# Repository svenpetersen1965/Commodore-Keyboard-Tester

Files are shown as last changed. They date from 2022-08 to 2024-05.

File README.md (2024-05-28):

# Commodore-Keyboard-Tester
This is a tester for Commodore matrix keyboards for the following compurters:
* C64
* VIC-20
* PET/CBM
* C16
* C128
* C128D
* SX-64

It can measure the resistance of every single key, which requires a multimeter and two 4mm lab cables.

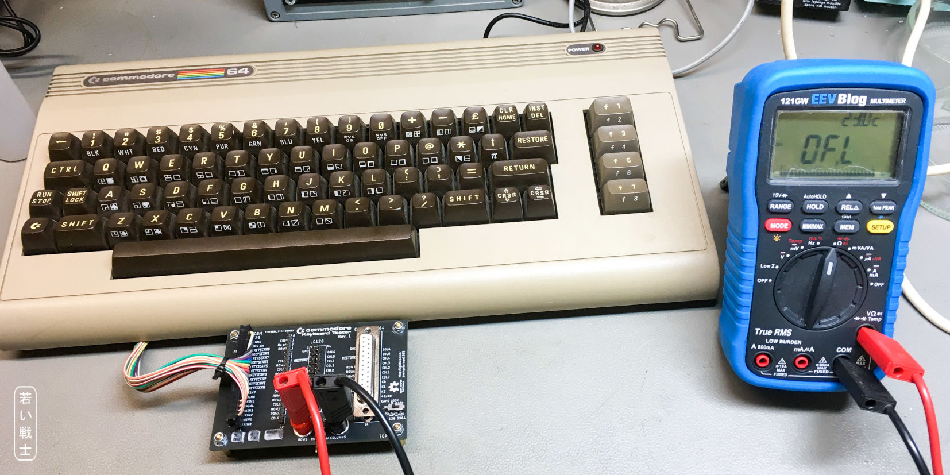
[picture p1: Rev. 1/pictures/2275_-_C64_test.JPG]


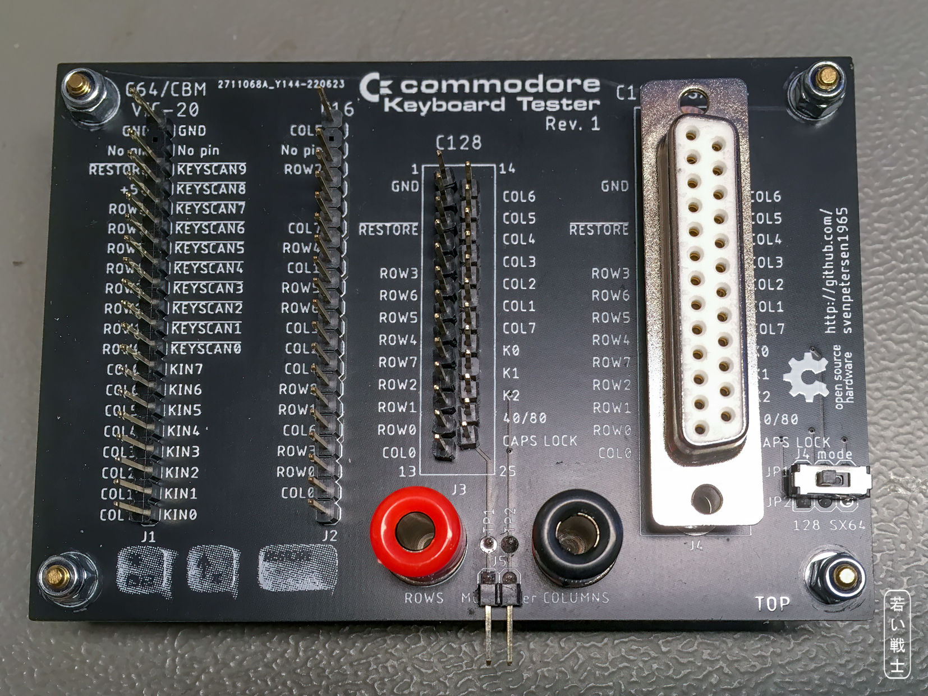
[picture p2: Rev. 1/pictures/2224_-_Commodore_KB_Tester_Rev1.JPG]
Commodore Keyboard Tester


# Case (3D printed)
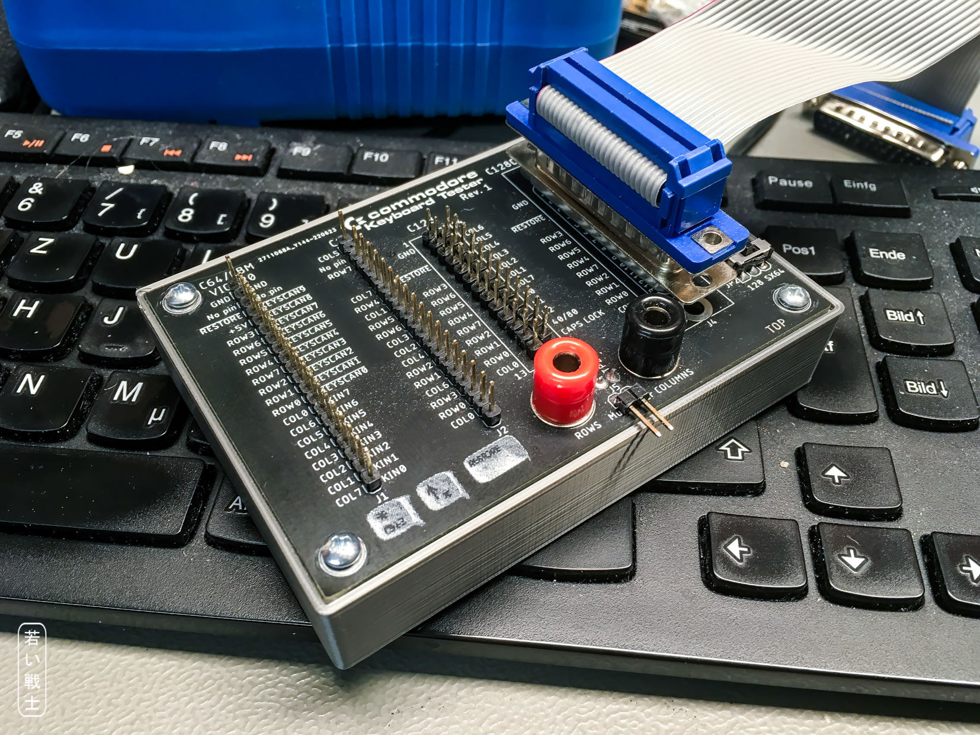
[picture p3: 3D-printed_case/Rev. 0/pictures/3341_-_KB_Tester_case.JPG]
Commodore Keyboard Tester


The 3D printed case offers a better protection of the bottom side and looks a bit nicer, than the stand off solution. It works with all released versions (100mm x
70mm PCB). 

Recommended screws are 4 each of C2.9 x 6.5 (self cutting, DIN 7981). The drill diameter is 2.5mm.

In case it is desired to use 2mm lab jacks, a 3mm deeper case (Rev. 2) has been released.

# Rev. 2
Rev. 2 is mainly a nicer looking silkscreen, than Rev. 1. Technically, this version is not any upgrade. 

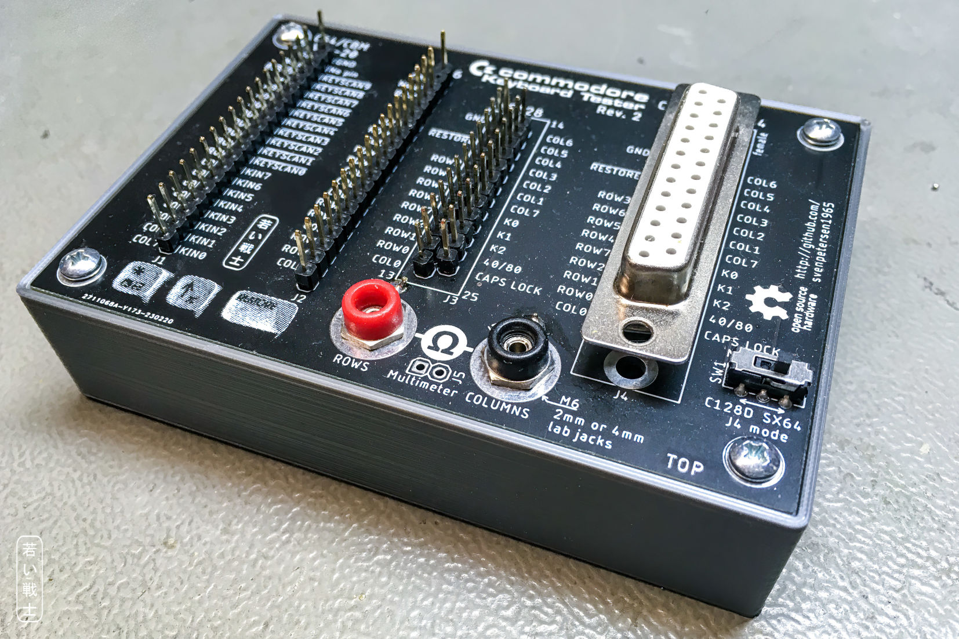
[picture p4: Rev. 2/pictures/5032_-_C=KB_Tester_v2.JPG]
Commodore Keyboard Tester Rev. 2


# Info about rejuvenation keyboard rubber
As I said in the documentation, one reason for bad keys is the oil that is sweating from the conductive rubbers over the decades. This can be removed by soaking the rubbers in a mild caustic solution for at least 24hours.

Jeff Birt did some great research on this topic, which cou can find here:

<a href="https://youtu.be/n9gGz2n-sBU">Hey Birt! (Youtube): Resistance is futile Rejuvenating vintage computer keyboard key contacts</a>

Instead of ammonia, I am using a lye (NaOH) solution and I wrote somethng about it on my website:

<a href="http://tech.guitarsite.de/conductive_rubber.html">Rejuvenating The Conductive Rubber In a (Commodore) Keyboard</a>

After treating the keyboard rubbers, it might make sense to measure their resistance before installing them in the keyboard again. I found Jeff Birt's ficture quite nice for doing so. 

https://github.com/Jeff-Birt/C64_C128_Amiga_Mitsumi_Key_Tester

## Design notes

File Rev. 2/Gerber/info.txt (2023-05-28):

      
       Board: Commodore_KB_Tester
       Rev.:  2
  
       Files:
       ======
  
       All Gerber files are generated in extended gerber format (RS274X)
       *.TOP        : Film top copper
       *.BOT        :  -"- bottom copper
       *.STC        :  -"- top soldermask 
       *.STS        :  -"- bottom soldermask
       *.PLC        :  -"- silk screen top
       *.DK         : Drills plated Through (Excellon)
       *.NDK        : Drills not plated Through (Excellon)
       *.OUT        : Board outline

       Board Size:
       ===========
       Length     :   100.0 mm
       Width      :   70.0 mm
       Thickness  :   1.6 mm
       Material   :   FR 4
       Copper     :   35 um
       Surface    :   HASL
       
       Remarks:
       ========

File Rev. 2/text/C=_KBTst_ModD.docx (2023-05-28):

Commodore Keyboard Tester Rev. 2

Module Description

# 1. Introduction

They keyboard tester aims at testing Commodore matrix keyboards with an ohm meter (multi meter) without disassembling the keyboard.

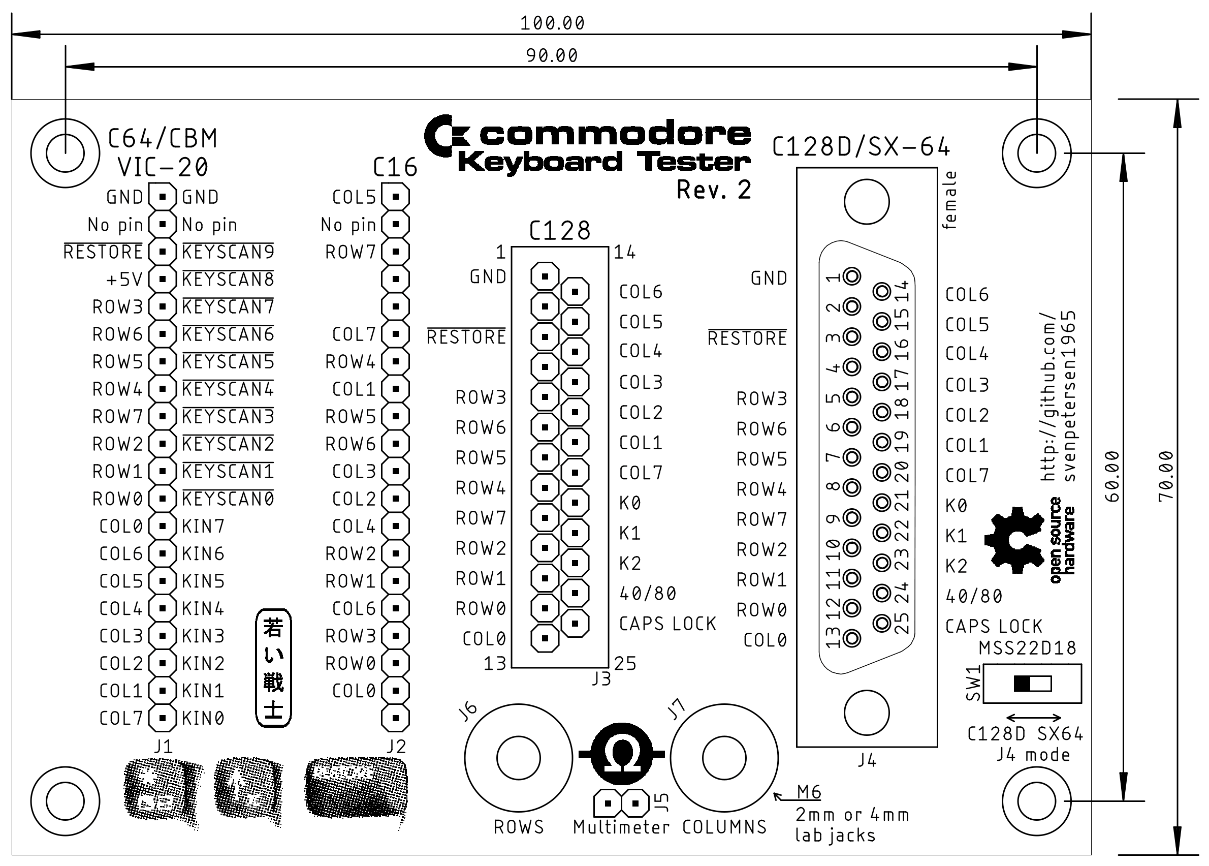
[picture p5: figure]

Figure 1: Commodore Keyboard Tester Rev. 1

Each button in a matrix keyboard is connected to one column and one row signal. If all rows are connected to on lead of the multi meter and all columns are connected to the other lead of the multimeter, a key press will connect both sides, no matter, which key it is. Assuming, that no 2nd key is pressed, the reading on the ohm meter is the impedance of the pressed key plus the traces and cables.

# 2. Keyboard Matrices

## 2.1. C64/VIC-20/PET

The VIC-20, C64, and PET (Graphic and Business Keyboard) have the same connector (a 20 pin header with the 2nd pin missing as a keying for the direction.

Connection | C64/VIC20 | Pin | Pin | PET/CBM | Connection
COLS | GND | 1 | 12 | GND | (COLS)
- | No pin | 2 | 11 | No pin | -
ROWS | RESTORE | 3 | 10 | | ROWS
(ROWS) | +5V | 4 | 9 | | ROWS
ROWS | ROW3 | 5 | 8 | | ROWS
ROWS | ROW6 | 6 | 7 | | ROWS
ROWS | ROW5 | 7 | 6 | | ROWS
ROWS | ROW4 | 8 | 5 | | ROWS
ROWS | ROW7 | 9 | 4 | | ROWS
ROWS | ROW2 | 10 | 3 | | ROWS
ROWS | ROW1 | 11 | 2 | | ROWS
ROWS | ROW0 | 12 | 1 | | ROWS
COLS | COL0 | 13 | J | KIN7 | COLS
COLS | COL6 | 14 | H | KIN6 | COLS
COLS | COL5 | 15 | F | KIN5 | COLS
COLS | COL4 | 16 | E | KIN4 | COLS
COLS | COL3 | 17 | D | KIN3 | COLS
COLS | COL2 | 18 | C | KIN2 | COLS
COLS | COL1 | 19 | B | KIN1 | COLS
COLS | COL7 | 20 | A | KIN0 | COLS

The PET/CBM-Keyboard connector has an unusual pin numbering, but the table above shows, which pin numbers are identical. Pin 4 of the C64/VIC-20 connector (+5) is not connected within the keyboard and pin 12 (GND) of the PET/CBM keyboard. Connecting them the way shown in the table, allows testing both kinds of keyboard at the same pin header.

## 2.2. C16

The C16 keyboard matrix is quite different from the C64/VIC-20 keyboard. It is missing the RESTORE key and the +5V and no key is referenced to GND.

Connection | Signal | Pin
COLS | COL5 | 1
- | No pin | 2
ROWS | ROW7 | 3
- | GND | 4
- | - | 5
COLS | COL7 | 6
ROWS | ROW4 | 7
COLS | COL1 | 8
ROWS | ROW5 | 9
ROWS | ROW6 | 10
COLS | COL3 | 11
COLS | COL2 | 12
COLS | COL4 | 13
ROWS | ROW2 | 14
ROWS | ROW1 | 15
COLS | COL6 | 16
ROWS | ROW3 | 17
ROWS | ROW0 | 18
COLS | COL0 | 19
- | - | 20

## 2.3. C128

The C128 has a keyboard connector, which is a pin header (0.65 sq) that fits on the footprint of a female D-SUB connector. The pin numbering is identical to such a D-SUB connector. According to Bil Herd, this pin header was custom made for Commodore.

Connection | Signal | Pin | Pin | Signal | Connection
COLS | GND | 1 | 14 | COL6 | COLS
- | No Pin | 2 | 15 | COL5 | COLS
ROWS | | 3 | 16 | COL4 | COLS
- | +5V | 4 | 17 | COL3 | COLS
ROWS | ROW3 | 5 | 18 | COL2 | COLS
ROWS | ROW6 | 6 | 19 | COL1 | COLS
ROWS | ROW5 | 7 | 20 | COL7 | COLS
ROWS | ROW4 | 8 | 21 | K0 | COLS
ROWS | ROW7 | 9 | 22 | K1 | COLS
ROWS | ROW2 | 10 | 23 | K2 | COLS
ROWS | ROW1 | 11 | 24 | 40/80 | ROWS
ROWS | ROW0 | 12 | 25 | CAPS LOCK | ROWS
COLS | COL0 | 13 | - | - | -

, 40/80 and CAPS LOCK are referenced to GND (Pin 1). K0…K2 are additional columns, they are connected to the 24 extra keys, which are not present in the C64 mode.

## 2.4. C128D & SX-64

The SX-64 keyboard cable does not fit with the female D-SUB 25 connector. Testing an SX-25 Keyboard requires an extra cable: two male D-SUB 25 connectors on a ribbon cable. This allows to connect the tester directly to the keyboard.

Connection | C128D | Pin | SX-64 | Connection
COLS | GND | 1 | GND | COLS
- | No Pin | 2 | No Pin | -
ROWS | | 3 | | ROWS
- | +5V | 4 | +5V | -
ROWS | ROW3 | 5 | ROW3 | ROWS
ROWS | ROW6 | 6 | ROW6 | ROWS
ROWS | ROW5 | 7 | ROW5 | ROWS
ROWS | ROW4 | 8 | ROW4 | ROWS
ROWS | ROW7 | 9 | ROW7 | ROWS
ROWS | ROW2 | 10 | ROW2 | ROWS
ROWS | ROW1 | 11 | ROW1 | ROWS
ROWS | ROW0 | 12 | ROW0 | ROWS
COLS | COL0 | 13 | COL0 | COLS
COLS | COL6 | 14 | COL6 | COLS
COLS | COL5 | 15 | COL5 | COLS
COLS | COL4 | 16 | COL4 | COLS
COLS | COL3 | 17 | COL3 | COLS
COLS | COL2 | 18 | COL2 | COLS
COLS | COL1 | 19 | COL1 | COLS
COLS | COL7 | 20 | COL7 | COLS
COLS | K0 | 21 | SHIFT LOCK | ROWS
COLS | K1 | 22 | LED (+) | COLS
COLS | K2 | 23 | GND | COLS
ROWS | 40/80 | 24 | GND | COLS
ROWS | CAPS LOCK | 25 | n.c. | (ROWS)

n.c.: not connected

, 40/80, CAPS LOCK and SHIFT LOCK are referenced to GND (Pin 1). The LED (+) is also referenced to GND, it will not be tested. Pin 21 and pin 24 are different for the C128D and the SX-64. They require to be configurable with jumpers or a slide switch (option).

# 3. Assembly

## 3.1. The C64 and C16 connector (J1 and J2)

These connectors are standard 20 pin headers with pin 2 pulled out. It could be cut off, I prefer to pull it with pliers, though.

## 3.2. The C128 connector (J3)

J3 is actually a square pin header (0.65mm) with the footprint of a 25 pin DSub (male). My first attempt was cutting the frame off a vertical DSub connector and using it for J3, but it did not work out, since the pins of the DSub are too thick to fit into the keyboard connector. It is not helpful to ruin the keyboard connector.

I had a short conversation with Bil Herd (the C128 engineer at Commodore) about the pin header. He said, it was custom made for Commodore. So, it cannot be sourced anywhere.

A DSub connector has a pin pitch of 110 mil, so the standard 100 mil pin header does not fit, either. A solution, that is not beautiful, but practical is using 25 single pin headers and insert them into the keyboard connector before soldering.

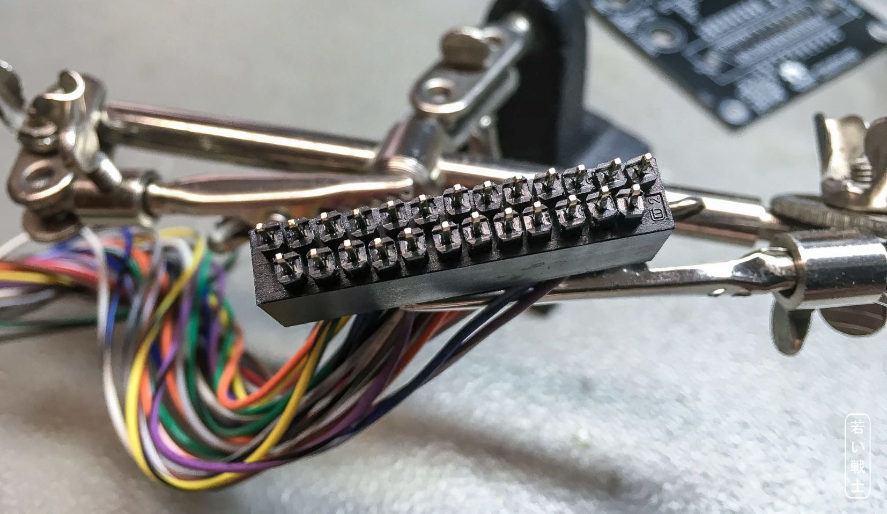
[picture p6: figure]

Figure 2: Alignment of the pins in a C128 keyboard connector

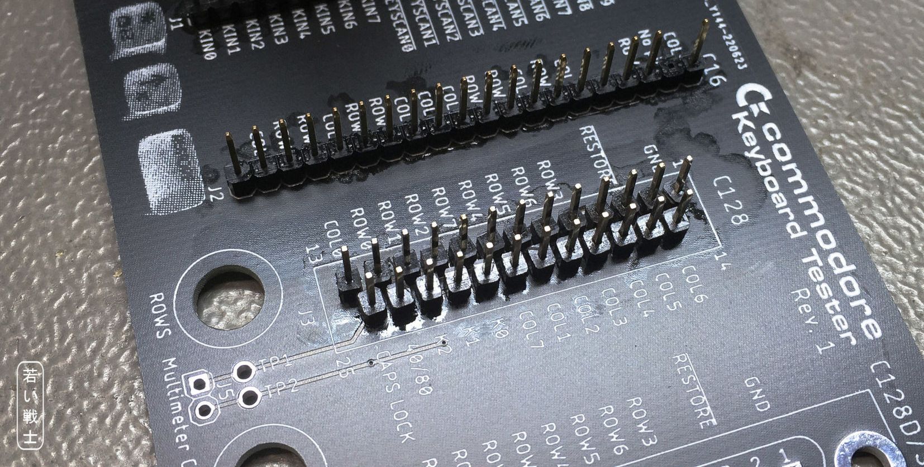
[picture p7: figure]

Figure 3: Soldered in C128 keyboard header (25 single pin headers) PCB Rev. 1

## 3.3. The C128D/SX-64 connector (J4)

This is a 25p DSub (female) connector. No further comments required.

## 3.4. 2mm/4mm Lab Jack for the Multimeter

The lab jacks for the multimeter have to be connected the solder pads beside the Lab jack footptint with a short piece of wire. Some sorts are pretty hard to solder and tend to deform/melt. It is a good idea to remove as many parts as possible before soldering.

Non-insulated lab jacks can be just screwed in. The big solder pad is connected to the circuitry, so there is no extra cable required.

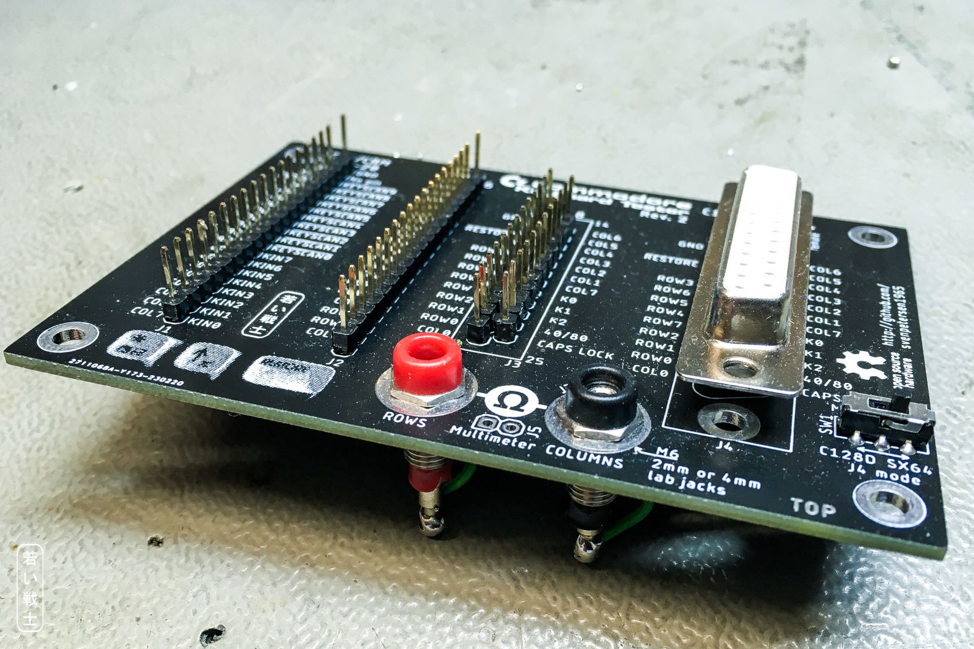
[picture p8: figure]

Figure 4: 2mm jacks for the multimeter

The lab jacks should be installed with all plastic parts on the component side of the PCB to keep the profile below the PCB as low as possible. 2mm and 4mm lab jacks with an M6 thread are suitable.

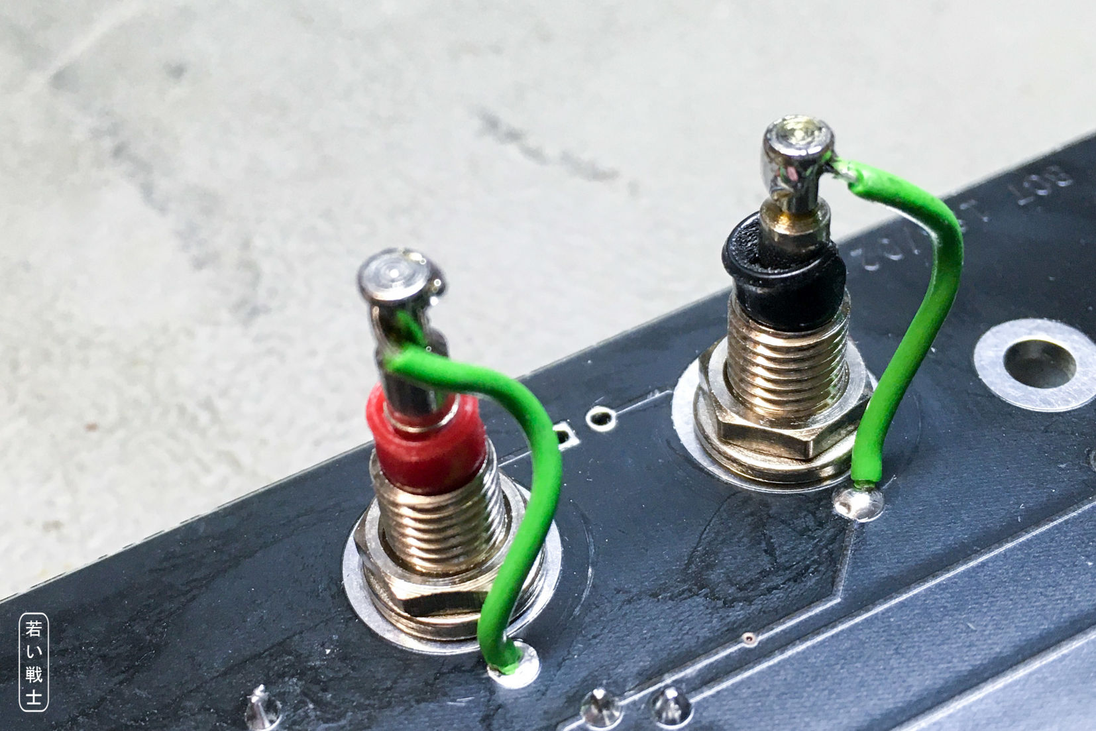
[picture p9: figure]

Figure 5: 2mm lab jack connected with a piece of wire

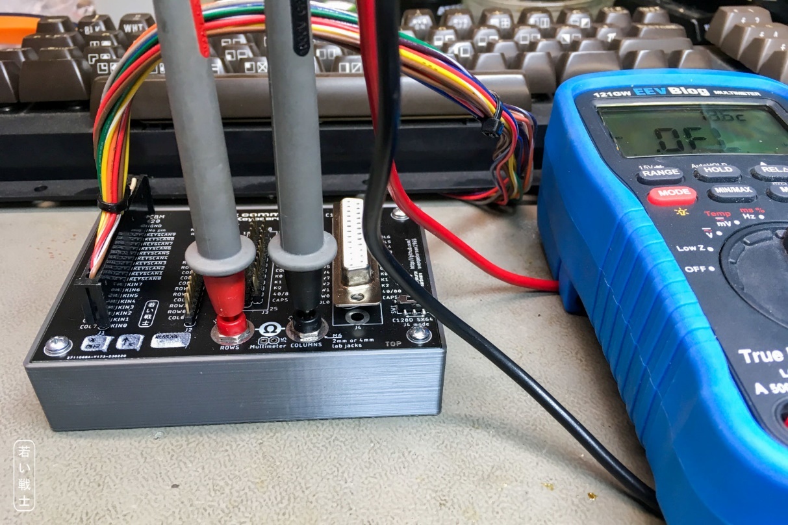
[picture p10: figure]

Figure 6: Keyboard Tester with 2mm jacks "in situ"

2mm lab jacks directly connect to the leads of a multimeter.

## 3.5. Multimeter Pin Header (J5)

J5 is a standard pin header, which can be either vertical or a 90°-type. It is optional. I am using it with a one pin Dupont connector on a cable with a 4mm plug and that is pretty handy, too. However, J5 is in parallel with the lab jacks and it is optional.

## 3.6. The C128D/SX-64 selection switch

The mini slide switch has a 2.54mm pitch in each row of pins. The distance of the rows is off pitch, though. This way, it also fits two 3pin 2.54mm jumpers.

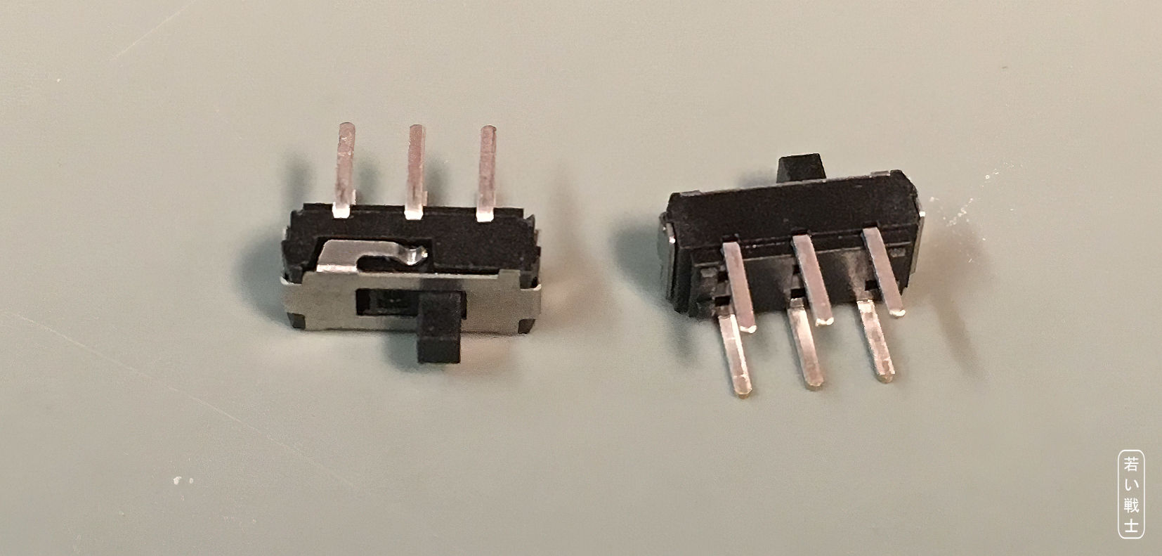
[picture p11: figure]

Figure 7: Mini slide switch

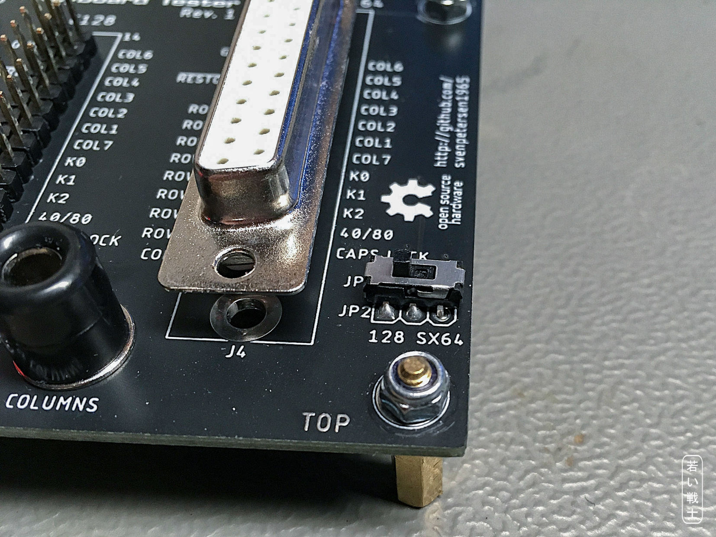
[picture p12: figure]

Figure 8: Slide switch placed instead of JP1 and JP2

These mini slide switches can be found on Amazon, Ebay and AliExpress. A possible search term is “mini slide switch dpdt” or “MSS22D18”, which will not show these switches exclusively, but it should not be too hard to find the right ones.

## 3.7. The SX-64 Keyboard Cable

The original SX-64 keyboard cable does not fit with the female DSub on the Keyboard Tester, but a male

## 3.8. The 3D-printed case

For the 2mm lab jacks, the case needs to be 3mm deeper than for Rev. 0 and 1. If 4mm lab jacks are used, the Rev.0 case is still suitable (which saves a little bit of printing time.

Recommended screws: 4 each of 2.9mm x 6.5mm (self-taping) screws for sheet metal (C 2,9x6,5H, DIN 7981)

# 4. The Use of the Keyboard Tester

A multimeter is required for using this keyboard tester. A good impedance is between 0Ω and a few 100 Ω. Probably, a keyboard works with even up to 3kΩ, but I would consider it as critical. Also, the different computers use different interface chips (VIA, CIA etc.) and even scanning is a bit different, so the limit for “good” might be different. In my opinion, everything above 600Ω requires inspection. 2kΩ might still work.

The keyboard is connected to the proper pin header, the multimeter is set to continuity test (“beeper”) mode or a low Ohms range. Every single key of the keyboard is pressed, one at a time and the value is read from the multimeter. If a key does not produce a reading in continuity test mode, switch to normal Ohms mode. This is slower, but sometimes the range in continuity test mode is too low to show a reading. The 121GW will display up to 550Ω, while the VC160 displays up to 400Ω in the continuity tester mode.

With the 121GW, it is possible to set the range from auto to kΩ, which will speed up the measurement from about 5 seconds to “almost immediate”.

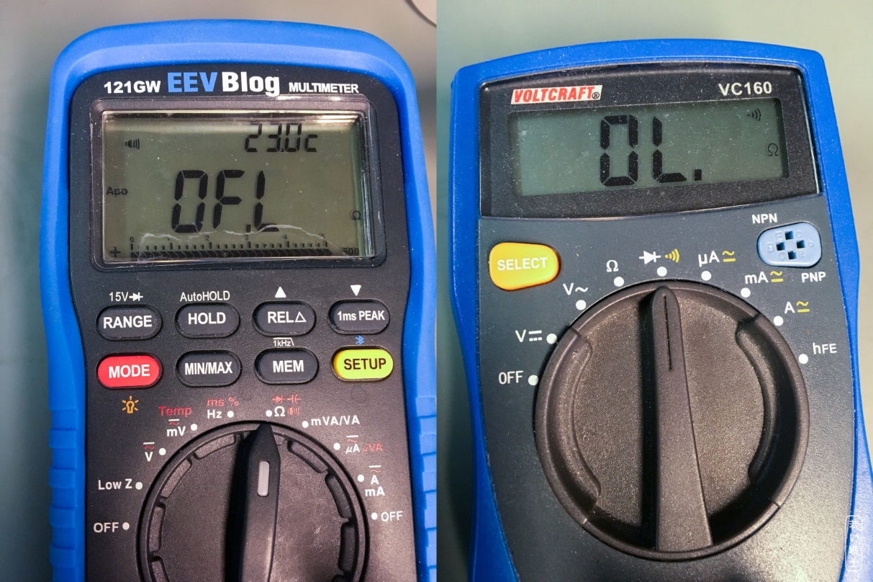
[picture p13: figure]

Figure 9: Multimeters in continuity test mode

A key is high impedance, and now?

There are different reasons for that, all require opening the keyboard and inspecting the thing.

Sometimes, dirt has collected under the failing key. That can be fixed easily. Carefully remove the dust/dirt. You can use isopropanol (rubbing alcohol, IPA) on the conductive rubbers and also on a golden surface PCB. Do not rub IPA hard on carbon contact key pads. The carbon contact could be damaged. It requires a more careful use of IPA or maybe even just demineralized water without a detergent.

Many keyboard PCBs use a “two layers on one side” technology with conductive bridges adhered to some contact points, that are crossing several copper traces. Those can get high impedance. I have fixed this kind of problems with soldering botch wires to the poorly contacted copper trace. Those botch wires should run on the bottom side of the PCB to not mechanically interfere with the keyboard. This might require drilling little holes for switching sides.

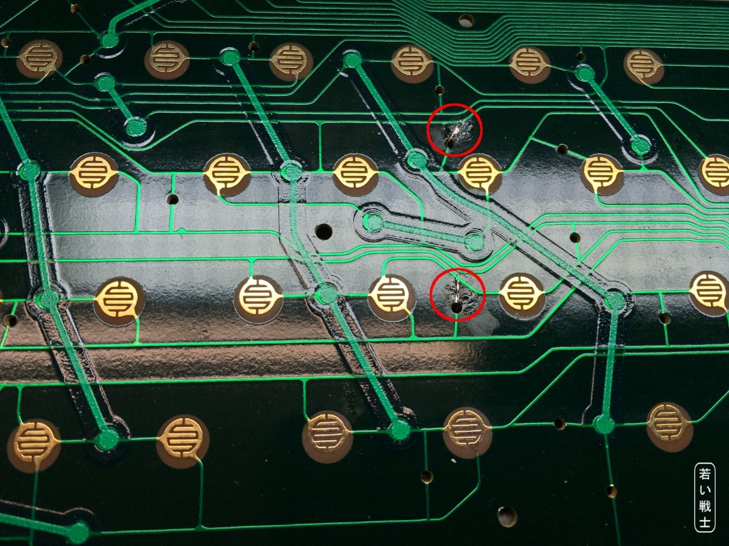
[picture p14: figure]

Figure 10: Botch wire repair (top side) solder joints

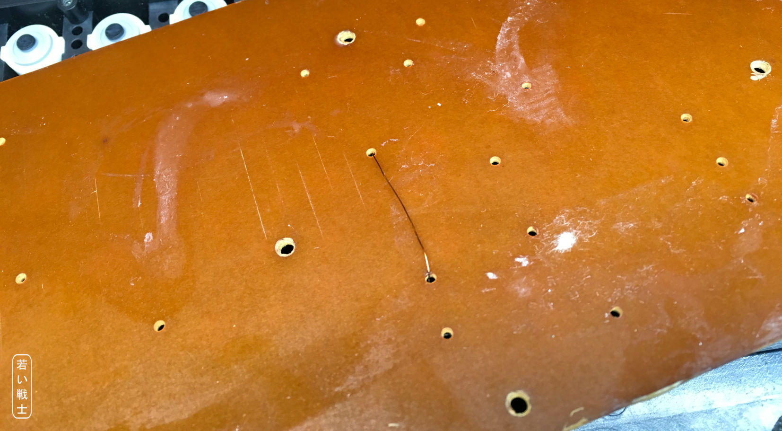
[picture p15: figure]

Figure 11: Botch wire repair (bottom side)

In this case, I have made use of the already existing drills in the PCB.

Jeff Birt from the “Hey Birt!” Youtube channel has done some research on aging conductive keyboard rubbers. He found out, that high impedance keyboard rubbers are caused by oils, that are escaping the rubber. He said, that removing theses oils requires a mild caustic solution.

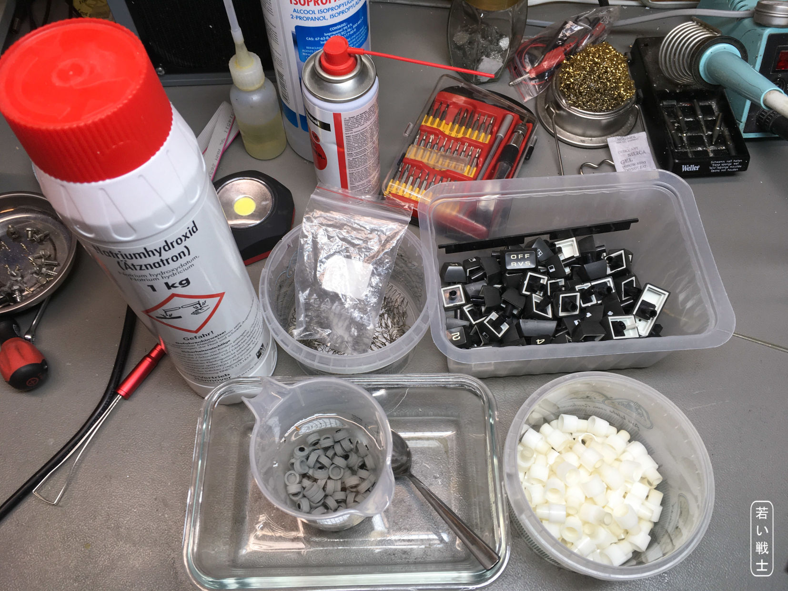
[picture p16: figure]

Figure 12: Rejuvenation the keyboard rubbers with a NaOH (lye) solution

I am using a lye (NaOH/sodium hydroxide) solution (1 teaspoon in 125ml of demineralized water). The keyboard rubbers need to be submerged in it for about 24 hours. After this treatment, they should be rinsed carefully (use a big enough sieve to not lose any) in tap water and finally in demineralized water. Finally, let it them dry on a kitchen paper over night.

This is quite a bit of work, but well worth it. Once, I had tried to get the rubbers out without disassembling the keyboard on a C16 keyboard and accidentally destroyed one. Also, it might be good to clean every single part of a keyboard on a newly acquired computer, anyway.

# 5. Revision History

## 5.1. Rev. 0

- The prototype worked with all, except the SX-64 Keyboard.

## 5.2. Rev. 0 → Rev. 1

- Jumper/Switch added for configuring the C128D or the SX-64 keyboard
- Fully functional

## 5.3. Rev. 1 → Rev. 2

- Improvement of the silk screen print
- The functionality is identical to Rev. 1

C=_KBTst_ModD.docx 28.05.2023 13:55 Drafted by Sven Petersen Page 2 of 2 Doc.-No.: 188-6-01-02

C=_KBTst_ModD.docx 28.05.2023 13:55 Drafted by Sven Petersen Page 1 of 1 Doc.-No.: 000-6-00-00

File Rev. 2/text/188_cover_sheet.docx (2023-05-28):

Project Documentation

Project number: 188

Revision: 2

Date: 29.01.2023


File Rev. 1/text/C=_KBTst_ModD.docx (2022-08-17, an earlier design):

Commodore Keyboard Tester Rev. 1

Module Description

# Introduction

They keyboard tester aims at testing Commodore matrix keyboards with an ohm meter (multi meter) without disassembling the keyboard.

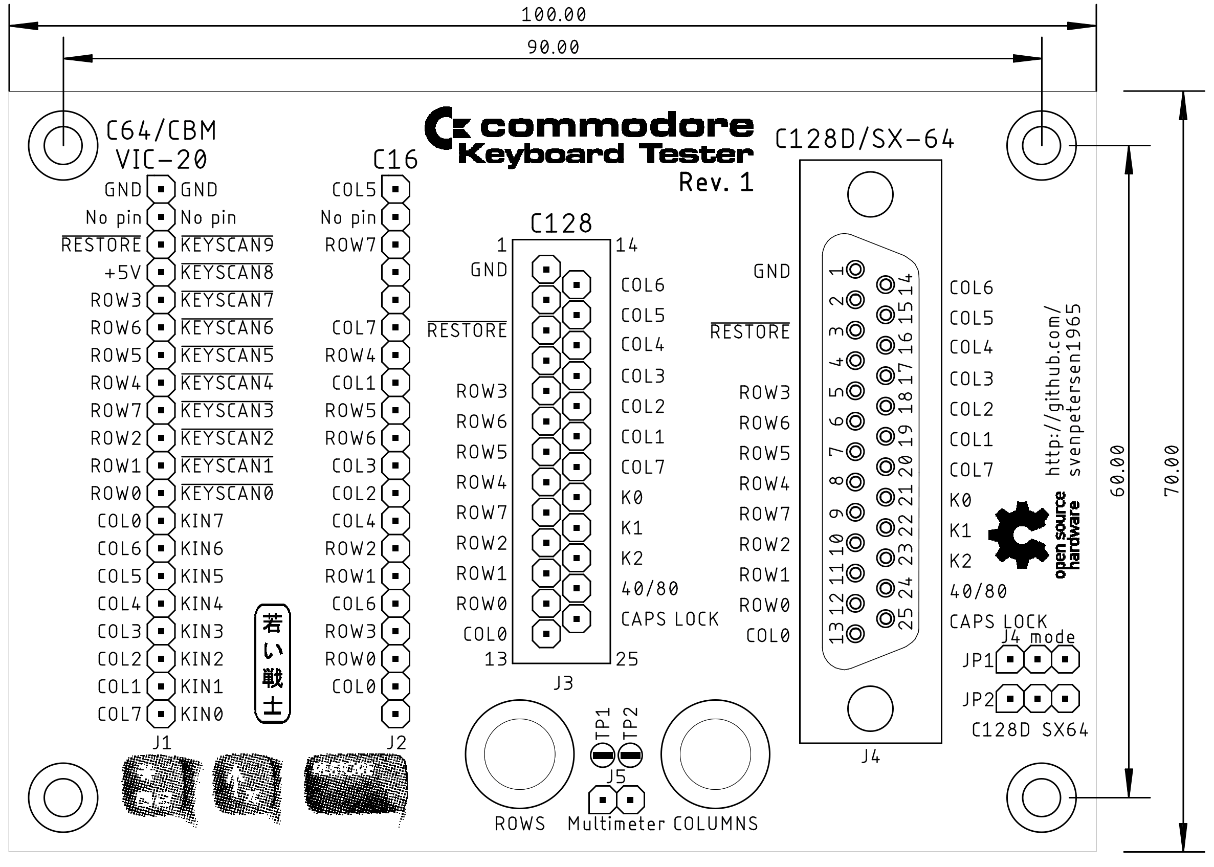
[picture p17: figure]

Figure 1: Commodore Keyboard Tester Rev. 1

Each button in a matrix keyboard is connected to one column and one row signal. If all rows are connected to on lead of the multi meter and all columns are connected to the other lead of the multimeter, a key press will connect both sides, no matter, which key it is. Assuming, that no 2nd key is pressed, the reading on the ohm meter is the impedance of the pressed key plus the traces and cables.

# Keyboard Matrices

## C64/VIC-20/PET

The VIC-20, C64, and PET (Graphic and Business Keyboard) have the same connector (a 20 pin header with the 2nd pin missing as a keying for the direction.

Connection | C64/VIC20 | Pin | Pin | PET/CBM | Connection
COLS | GND | 1 | 12 | GND | (COLS)
- | No pin | 2 | 11 | No pin | -
ROWS | RESTORE | 3 | 10 | | ROWS
(ROWS) | +5V | 4 | 9 | | ROWS
ROWS | ROW3 | 5 | 8 | | ROWS
ROWS | ROW6 | 6 | 7 | | ROWS
ROWS | ROW5 | 7 | 6 | | ROWS
ROWS | ROW4 | 8 | 5 | | ROWS
ROWS | ROW7 | 9 | 4 | | ROWS
ROWS | ROW2 | 10 | 3 | | ROWS
ROWS | ROW1 | 11 | 2 | | ROWS
ROWS | ROW0 | 12 | 1 | | ROWS
COLS | COL0 | 13 | J | KIN7 | COLS
COLS | COL6 | 14 | H | KIN6 | COLS
COLS | COL5 | 15 | F | KIN5 | COLS
COLS | COL4 | 16 | E | KIN4 | COLS
COLS | COL3 | 17 | D | KIN3 | COLS
COLS | COL2 | 18 | C | KIN2 | COLS
COLS | COL1 | 19 | B | KIN1 | COLS
COLS | COL7 | 20 | A | KIN0 | COLS

The PET/CBM-Keyboard connector has an unusual pin numbering, but the table above shows, which pin numbers are identical. Pin 4 of the C64/VIC-20 connector (+5) is not connected within the keyboard and pin 12 (GND) of the PET/CBM keyboard. Connecting them the way shown in the table, allows testing both kinds of keyboard at the same pin header.

## C16

The C16 keyboard matrix is quite different from the C64/VIC-20 keyboard. It is missing the RESTORE key and the +5V and no key is referenced to GND.

Connection | Signal | Pin
COLS | COL5 | 1
- | No pin | 2
ROWS | ROW7 | 3
- | GND | 4
- | - | 5
COLS | COL7 | 6
ROWS | ROW4 | 7
COLS | COL1 | 8
ROWS | ROW5 | 9
ROWS | ROW6 | 10
COLS | COL3 | 11
COLS | COL2 | 12
COLS | COL4 | 13
ROWS | ROW2 | 14
ROWS | ROW1 | 15
COLS | COL6 | 16
ROWS | ROW3 | 17
ROWS | ROW0 | 18
COLS | COL0 | 19
- | - | 20

## C128

The C128 has a keyboard connector, which is a pin header (0.65 sq) that fits on the footprint of a female D-SUB connector. The pin numbering is identical to such a D-SUB connector. According to Bil Herd, this pin header was custom made for Commodore.

Connection | Signal | Pin | Pin | Signal | Connection
COLS | GND | 1 | 14 | COL6 | COLS
- | No Pin | 2 | 15 | COL5 | COLS
ROWS | | 3 | 16 | COL4 | COLS
- | +5V | 4 | 17 | COL3 | COLS
ROWS | ROW3 | 5 | 18 | COL2 | COLS
ROWS | ROW6 | 6 | 19 | COL1 | COLS
ROWS | ROW5 | 7 | 20 | COL7 | COLS
ROWS | ROW4 | 8 | 21 | K0 | COLS
ROWS | ROW7 | 9 | 22 | K1 | COLS
ROWS | ROW2 | 10 | 23 | K2 | COLS
ROWS | ROW1 | 11 | 24 | 40/80 | ROWS
ROWS | ROW0 | 12 | 25 | CAPS LOCK | ROWS
COLS | COL0 | 13 | - | - | -

, 40/80 and CAPS LOCK are referenced to GND (Pin 1). K0…K2 are additional columns, they are connected to the 24 extra keys, which are not present in the C64 mode.

## C128D & SX-64

The SX-64 keyboard cable does not fit with the female D-SUB 25 connector. Testing an SX-25 Keyboard requires an extra cable: two male D-SUB 25 connectors on a ribbon cable. This allows to connect the tester directly to the keyboard.

Connection | C128D | Pin | SX-64 | Connection
COLS | GND | 1 | GND | COLS
- | No Pin | 2 | No Pin | -
ROWS | | 3 | | ROWS
- | +5V | 4 | +5V | -
ROWS | ROW3 | 5 | ROW3 | ROWS
ROWS | ROW6 | 6 | ROW6 | ROWS
ROWS | ROW5 | 7 | ROW5 | ROWS
ROWS | ROW4 | 8 | ROW4 | ROWS
ROWS | ROW7 | 9 | ROW7 | ROWS
ROWS | ROW2 | 10 | ROW2 | ROWS
ROWS | ROW1 | 11 | ROW1 | ROWS
ROWS | ROW0 | 12 | ROW0 | ROWS
COLS | COL0 | 13 | COL0 | COLS
COLS | COL6 | 14 | COL6 | COLS
COLS | COL5 | 15 | COL5 | COLS
COLS | COL4 | 16 | COL4 | COLS
COLS | COL3 | 17 | COL3 | COLS
COLS | COL2 | 18 | COL2 | COLS
COLS | COL1 | 19 | COL1 | COLS
COLS | COL7 | 20 | COL7 | COLS
COLS | K0 | 21 | SHIFT LOCK | ROWS
COLS | K1 | 22 | LED (+) | COLS
COLS | K2 | 23 | GND | COLS
ROWS | 40/80 | 24 | GND | COLS
ROWS | CAPS LOCK | 25 | n.c. | (ROWS)

n.c.: not connected

, 40/80, CAPS LOCK and SHIFT LOCK are referenced to GND (Pin 1). The LED (+) is also referenced to GND, it will not be tested. Pin 21 and pin 24 are different for the C128D and the SX-64. They require to be configurable with jumpers or a slide switch (option).

# Assembly

## The C64 and C16 connector (J1 and J2)

These connectors are standard 20 pin headers with pin 2 pulled out. It could be cut off, I prefer to pull it with pliers, though.

## The C128 connector (J3)

J3 is actually a square pin header (0.65mm) with the footprint of a 25 pin DSub (male). My first attempt was cutting the frame off a vertical DSub connector and using it for J3, but it did not work out, since the pins of the DSub are too thick to fit into the keyboard connector. It is not helpful to ruin the keyboard connector.

I had a short conversation with Bil Herd (the C128 engineer at Commodore) about the pin header. He said, it was custom made for Commodore. So, it cannot be sourced anywhere.

A DSub connector has a pin pitch of 110 mil, so the standard 100 mil pin header does not fit, either. A solution, that is not beautiful, but practical is using 25 single pin headers and insert them into the keyboard connector before soldering.


Figure 2: Alignment of the pins in a C128 keyboard connector


Figure 3: Soldered in C128 keyboard header (25 single pin headers)

## The C128D/SX-64 connector (J4)

This is a 25p DSub (female) connector. No further comments required.

## 4mm Lab Jack for the Multimeter (TP1 & TP2)

The lab jacks for the multimeter have to be connected to TP1 and TP2 with a short piece of wire. Some sorts are pretty hard to solder and tend to deform/melt. It is a good idea to remove as many parts as possible before soldering.

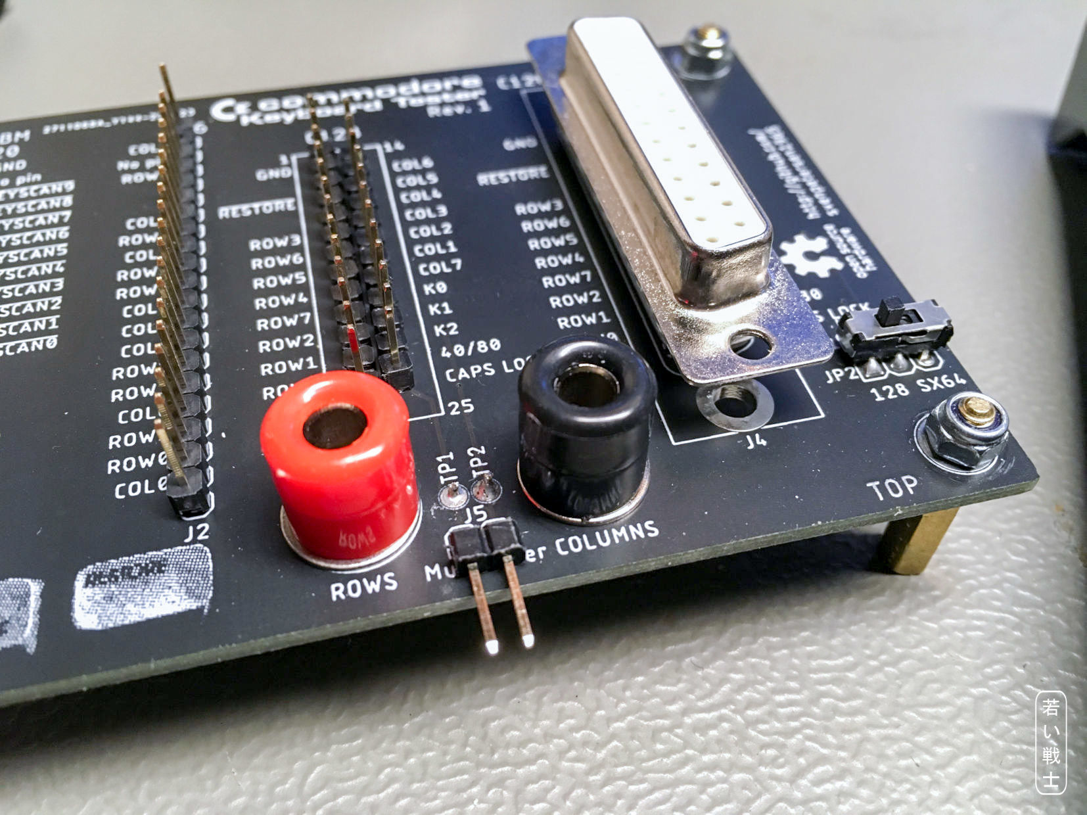
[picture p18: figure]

Figure 4: 4mm jacks for the multimeter

The jacks should be installed with all plastic parts on the component side of the PCB to keep the profile below the PCB as low as possible.

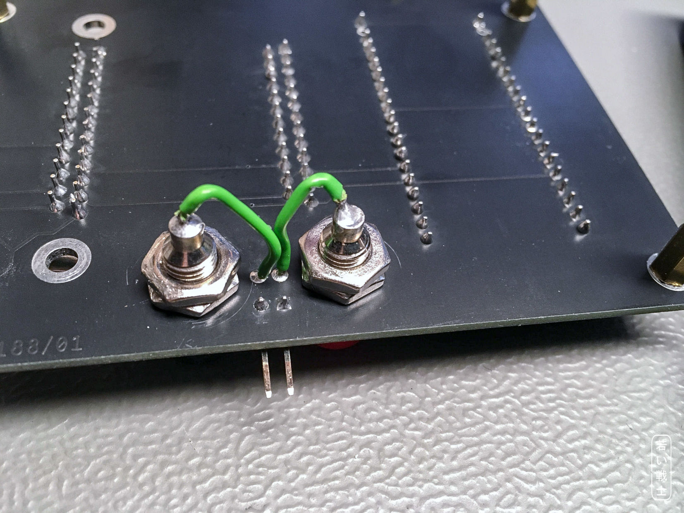
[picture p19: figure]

Figure 5: 4mm jack connected with a piece of wire

## Multimeter Pin Header (J5)

J5 is a standard pin header, which can be either vertical or a 90° type. It is optional. I am using it with a one pin Dupont connector on a cable with a 4mm plug and that is pretty handy, too. However, J5 is in parallel with the lab jacks and it is optional.

## The C128D/SX-64 selection jumpers JP1 and JP2

These jumpers have a certain distance, so a little slide switch (DPDT) also fits on both of them.


Figure 6: Slide switch placed instead of JP1 and JP2


Figure 7: Mini slide switch

These mini slide switches can be found on Amazon, Ebay and AliExpress. A possible search term is “mini slide switch dpdt”, which will not show these switches exclusively, but it should not be too hard to find the right ones.

## The SX-64 Keyboard Cable

The original SX-64 keyboard cable does not fit with the female DSub on the Keyboard Tester, but a male

# The Use of the Keyboard Tester

A multimeter is required for using this keyboard tester. A good impedance is between 0Ω and a few 100 Ω. Probably, a keyboard works with even up to 3kΩ, but I would consider it as critical. Also, the different computers use different interface chips (VIA, CIA etc.) and even scanning is a bit different, so the limit for “good” might be different. In my opinion, everything above 600Ω requires inspection. 2kΩ might still work.

The keyboard is connected to the proper pin header, the multimeter is set to continuity test (“beeper”) mode or a low Ohms range. Every single key of the keyboard is pressed, one at a time and the value is read from the multimeter. If a key does not produce a reading in continuity test mode, switch to normal Ohms mode. This is slower, but sometimes the range in continuity test mode is too low to show a reading. The 121GW will display up to 550Ω, while the VC160 displays up to 400Ω in the continuity tester mode.

With the 121GW, it is possible to set the range from auto to kΩ, which will speed up the measurement from about 5 seconds to “almost immediate”.


Figure 8: Multimeters in continuity test mode

A key is high impedance, and now?

There are different reasons for that, all require opening the keyboard and inspecting the thing.

Sometimes, dirt has collected under the failing key. That can be fixed easily. Carefully remove the dust/dirt. You can use isopropanol (rubbing alcohol, IPA) on the conductive rubbers and also on a golden surface PCB. Do not rub IPA hard on carbon contact key pads. The carbon contact could be damaged. It requires a more careful use of IPA or maybe even just demineralized water without a detergent.

Many keyboard PCBs use a “two layers on one side” technology with conductive bridges adhered to some contact points, that are crossing several copper traces. Those can get high impedance. I have fixed this kind of problems with soldering botch wires to the poorly contacted copper trace. Those botch wires should run on the bottom side of the PCB to not mechanically interfere with the keyboard. This might require drilling little holes for switching sides.


Figure 9: Botch wire repair (top side) solder joints


Figure 10: Botch wire repair (bottom side)

In this case, I have made use of the already existing drills in the PCB.

Jeff Birt from the “Hey Birt!” Youtube channel has done some research on aging conductive keyboard rubbers. He found out, that high impedance keyboard rubbers are caused by oils, that are escaping the rubber. He said, that removing theses oils requires a mild caustic solution.


Figure 11: Rejuvenation the keyboard rubbers with a NaOH (lye) solution

I am using a lye (NaOH/sodium hydroxide) solution (1 teaspoon in 125ml of demineralized water). The keyboard rubbers need to be submerged in it for about 24 hours. After this treatment, they should be rinsed carefully (use a big enough sieve to not lose any) in tap water and finally in demineralized water. Finally, let it them dry on a kitchen paper over night.

This is quite a bit of work, but well worth it. Once, I had tried to get the rubbers out without disassembling the keyboard on a C16 keyboard and accidentally destroyed one. Also, it might be good to clean every single part of a keyboard on a newly acquired computer, anyway.

# Revision History

## Rev. 0

- The prototype worked with all, except the SX-64 Keyboard.

## Rev. 0 → Rev. 1

- Jumper/Switch added for configuring the C128D or the SX-64 keyboard
- Fully functional

C=_KBTst_ModD.docx 16.08.2022 21:23 Drafted by Sven Petersen Page 2 of 2 Doc.-No.: 188-6-01-01

C=_KBTst_ModD.docx 16.08.2022 21:23 Drafted by Sven Petersen Page 1 of 1 Doc.-No.: 000-6-00-00

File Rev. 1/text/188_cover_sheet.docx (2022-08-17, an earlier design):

Project Documentation

Commodore Keyboard Tester

Project number: 188

Revision: 1

Date: 10.08.2022


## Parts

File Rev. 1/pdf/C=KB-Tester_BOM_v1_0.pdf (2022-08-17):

Pos. | Qty Value | Footprint | Ref.-No. | Comment
1 | 1 188-2-01-01 | 2 Layer | PCB Rev. 1 | 2 layer, Cu 35µ, HASL, 100mm x 77mm, 1.6mm FR4
2 | 2 1x3, 2.54mm pin header | 1X03 | JP1, JP2 | E.g. MPE Garry 087-1-003 (Reichelt MPE 087-1-003)
3 | 2 jumper, 2.54mm | jumper | (JP1), (JP2) | E.g. Reichelt MPE 149-1-002-F0
4 | 1 mini slide switch, 2.54mm,
| DPDT, through hole | | (JP1 & JP2) | Option. Replaces JP1, JP2 and jumpers. Ali Express, ebay,
| | | | Amazon, search term "MSS22D18", see module description
5 | 1 1x2, 2.54mm pin header | 1X02 | J5 | Option. E.g. MPE Garry 087-1-002 (Reichelt MPE 087-1-
| | | | 002)
6 | 2 1,3/2,0 | 1,3/2,0 | TP1, TP2 | 4mm panel jack, insulated, 6mm thread. E.g. Reichelt BIL
| | | | 30 RT (red), BIL 30 SW (black)
7 | 2 1x20, 2.54mm pin header 1X20 | J1, J2 | pin 2 removed, e.g. MPE Garry 087-01-020, Reichelt MPE
| | | | 087-1-020
8 | 1 C128 KB Header | C128KB_HEADE
| | R | J3 | assembled from 25 single pin headers (o0,64mm), see
| | | | module description (doc no. 188-6-01-**), e.g. Distrelec
| | | | 300-93-642 (RND 205-00622)
9 | 1 DSUB25 female/vertical
| PCB mount | DS25F-V | J4 | e.g. Reichelt D-SUB BU 25P
10 | 34cm ribbon cable, 25 pin,
| AWG28 | | drawing no. 188-3-01-01 | e.g. Reichelt AWG 28-25G 3M
11 | 2 Dsub 25/male, IDC | | drawing no. 188-3-01-01 | e.g. Reichelt D-SUB ST 25FB
12 | 4 15mm stand off, M3 | | | male/female
13 | 4 nuts, M3
13 | 5cm wire, 0.25m²/AWG24

## Commodore Keyboard Tester Rev. 1 Bill of Material Rev. 1.0

C=KB-Tester_BOM_v1_0.xlsx
Drafted by Sven Petersen | Page 1 of 1

17.08.2022 14:26
Doc.No.: 188-5-01-01.0

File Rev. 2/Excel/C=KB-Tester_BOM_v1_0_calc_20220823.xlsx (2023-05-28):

Commodore Keyboard Tester Rev. 1
Bill of Material Rev. 1.0 - Calculation 2022.08.23
Pos. | Qty | Value | €/ea | € | Comment
1 | 1 | 188-2-01-01 | 1.00 € | 1.00 € | 2 layer, Cu 35µ, HASL, 100mm x 77mm, 1.6mm FR4
2 | 0 | 1x3, 2.54mm pin header | 0.08 € | 0.00 € | E.g. MPE Garry 087-1-003 (Reichelt MPE 087-1-003)
3 | 0 | jumper, 2.54mm | 0.03 € | 0.00 € | E.g. Reichelt MPE 149-1-002-F0
4 | 1 | mini slide switch, 2.54mm, DPDT, through hole | 0.47 € | 0.47 € | Option. Replaces JP1, JP2 and jumpers. Ali Express, ebay, Amazon, search term "MSS22D18", see module description
5 | 0 | 1x2, 2.54mm pin header | 0.06 € | 0.00 € | Option. E.g. MPE Garry 087-1-002 (Reichelt MPE 087-1-002)
6 | 2 | 1,3/2,0 | 0.99 € | 1.98 € | 4mm panel jack, insulated, 6mm thread. E.g. Reichelt BIL 30 RT (red), BIL 30 SW (black)
7 | 2 | 1x20, 2.54mm pin header | 0.36 € | 0.72 € | pin 2 removed, e.g. MPE Garry 087-01-020, Reichelt MPE 087-1-020
8 | 1 | C128 KB Header | 0.76 € | 0.76 € | assembled from 25 single pin headers (o0,64mm), see module description (doc no. 188-6-01-**), e.g. Distrelec 300-93-642 (RND 205-00622)
9 | 1 | DSUB25 female/vertical PCB mount | 0.40 € | 0.40 € | e.g. Reichelt D-SUB BU 25P
10 | 1 | ribbon cable, 25 pin, AWG28 | 0.40 € | 0.40 € | e.g. Reichelt AWG 28-25G 3M
11 | 2 | Dsub 25/male, IDC | 0.89 € | 1.78 € | e.g. Reichelt D-SUB ST 25FB
12 | 4 | 15mm stand off, M3 | 0.33 € | 1.32 € | male/female
13 | 4 | nuts, M3 | 0.36 € | 1.44 €
13 | 1 | wire, 0.25m²/AWG24 | 0.05 € | 0.05 €
 |  | Total |  | 10.32 €

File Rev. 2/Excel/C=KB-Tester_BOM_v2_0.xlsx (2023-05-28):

Commodore Keyboard Tester Rev. 2
Bill of Material Rev. 2.0
Pos. | Qty | Value | Footprint | Ref.-No. | Comment
1 | 1 | 188-2-01-02 | 2 Layer | PCB Rev. 2 | 2 layer, Cu 35µ, HASL, 100mm x 77mm, 1.6mm FR4
2 | 2 | 1x3, 2.54mm pin header | 1X03 | JP1, JP2 | Option: E.g. MPE Garry 087-1-003 (Reichelt MPE 087-1-003)
3 | 2 | jumper, 2.54mm | jumper | (JP1), (JP2) | Option: E.g. Reichelt MPE 149-1-002-F0
4 | 1 | mini slide switch, 2.54mm, DPDT, through hole |  | (JP1 & JP2) | Option. Replaces JP1, JP2 and jumpers. Ali Express, ebay, Amazon, search term "MSS22D18", see module description
5 | 1 | 1x2, 2.54mm pin header | 1X02 | J5 | Option. E.g. MPE Garry 087-1-002 (Reichelt MPE 087-1-002)
6 | 2 | 4mm or 2mm panel jacks with 6mm thread | 1,3/2,0 | J6, J7 | 4mm panel jack, insulated, 6mm thread. E.g. Reichelt BIL 30 RT (red), BIL 30 SW (black). Or 2mm panel jacks
7 | 2 | 1x20, 2.54mm pin header | 1X20 | J1, J2 | pin 2 removed, e.g. MPE Garry 087-01-020, Reichelt MPE 087-1-020
8 | 1 | C128 KB Header | C128KB_HEADER | J3 | assembled from 25 single pin headers (o0,64mm), see module description (doc no. 188-6-01-**), e.g. Distrelec 300-93-642 (RND 205-00622)
9 | 1 | DSUB25 female/vertical PCB mount | DS25F-V | J4 | e.g. Reichelt D-SUB BU 25P
10 | 34cm | ribbon cable, 25 pin, AWG28 |  | drawing no. 188-3-01-01 | e.g. Reichelt AWG 28-25G 3M
11 | 2 | Dsub 25/male, IDC |  | drawing no. 188-3-01-01 | e.g. Reichelt D-SUB ST 25FB
12 | 4 | 15mm stand off, M3 |  |  | Option: male/female
13 | 4 | nuts, M3 |  |  | Option
13 | 5cm | wire, 0.25m²/AWG24 |  |  | if required

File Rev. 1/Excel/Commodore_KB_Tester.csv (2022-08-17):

Qty | Value | Device | Package | Parts | Description
4 |  | BOHR3,5 | BOHR3,5 | DRL1, DRL2, DRL3, DRL4
2 |  | DJUMPER | 1X03 | JP1, JP2
1 |  | PINHD-1X2 | 1X02 | J5
2 | 1,3/2,0 | 1,3/2,0 | 1,3/2,0 | TP1, TP2 | Testpunkt
2 | 1x20/mod | PINHD-1X20 | 1X20 | J1, J2
1 | C128 KB Header | C128_KBHEADER | C128KB_HEADER | J3
1 | DSUB25F/VPCB | DS25F-V-CL | DS25F-V | J4
1 | OPEN_SOURCE_HW | OPEN_SOURCE_HW | OPENHW | U$12

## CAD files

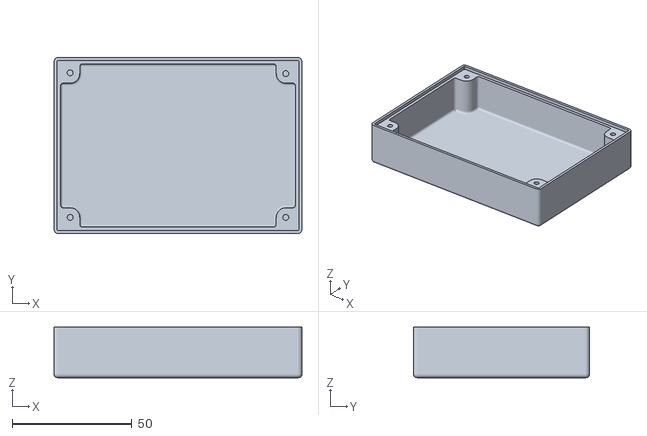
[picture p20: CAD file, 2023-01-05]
3D-printed_case/Rev. 0/STL/KB_Tester_bottom_shell.stl
103.5 x 73.5 x 21.1

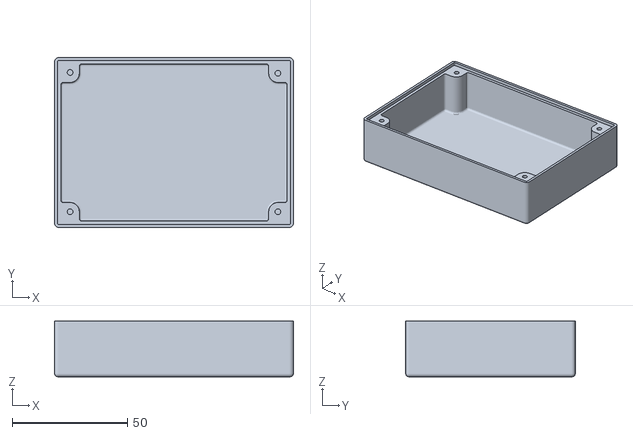
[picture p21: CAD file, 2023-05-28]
3D-printed_case/Rev. 2/stl/KB_Tester_bottom_shell_Rev2.stl
103.5 x 73.5 x 24.1

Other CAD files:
3D-printed_case/Rev. 0/Fusion 360/Commodore_KB_Tester v2.f3d
3D-printed_case/Rev. 2/Fusion360/Commodore_KB_Tester_Rev2 v2.f3d

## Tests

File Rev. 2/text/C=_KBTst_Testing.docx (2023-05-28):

Commodore Keyboard Tester Rev. 2

Testing

# 1. Test Setup

The test setup consisted of:

- A prototype of the keyboard tester rev. 1
- A multimeter (eevBlog 128GW)
- 2 4mm lab cables
- A working keyboard of the following computers: C64 VIC-20 CBM3016 graphic keyboard CBM8032 business keyboard C16 C128 C128D SX-64

The multimeter was set to Ohms, range 5kΩ.

# 2. Test Execution

## 2.1. C64

After connecting the keyboard, the meter showed OFL, which means “overflow” = the resistance is bigger than the range (open circuit).

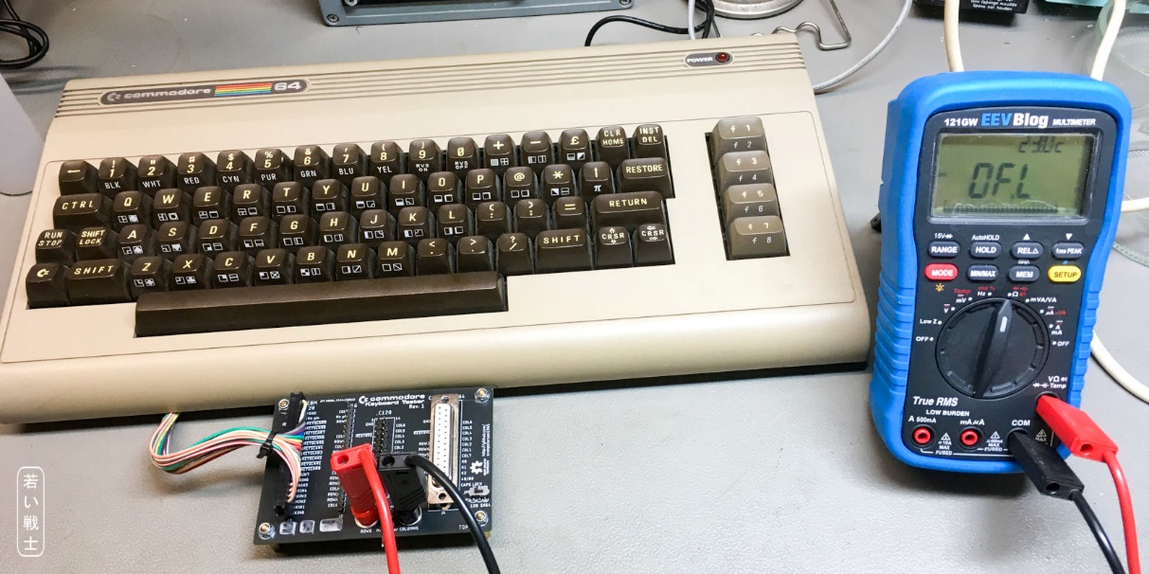
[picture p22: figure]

Figure 1: Testing the C64 keyboard

Every key produced a reading which was within the range.

## 2.2. VIC-20

After connecting the keyboard, the meter showed OFL.

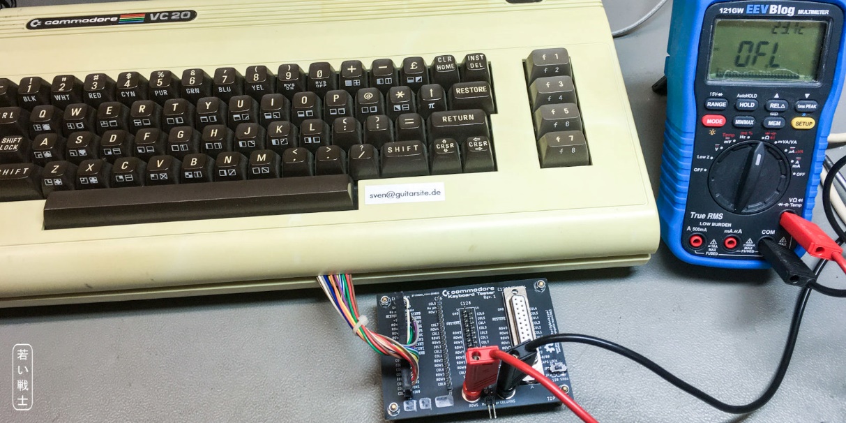
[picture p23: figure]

Figure 2: Testing the VIC-20 keyboard

Every key produced a reading which was within the range.

## 2.3. CBM3016 graphic keyboard

After connecting the keyboard, the meter showed OFL.

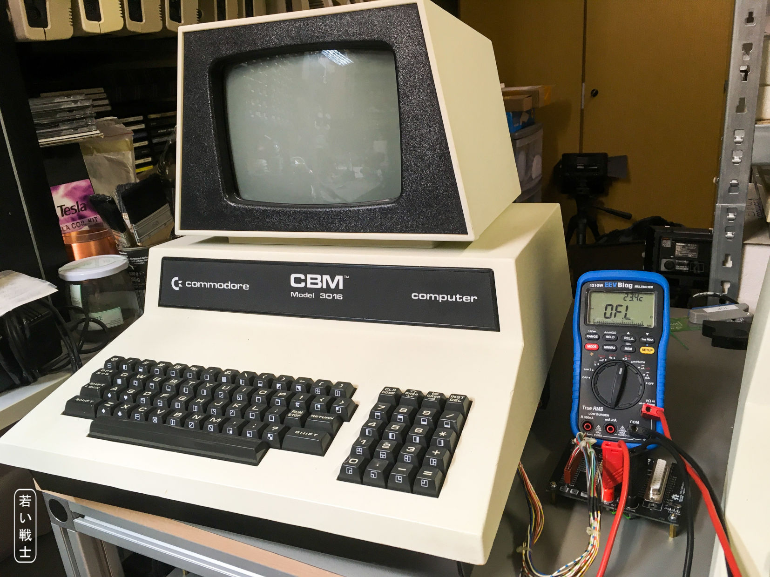
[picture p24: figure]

Figure 3: Testing the CBM3016 keyboard

Every key produced a reading which was within the range.

## 2.4. CBM8032 business keyboard

After connecting the keyboard, the meter showed OFL.

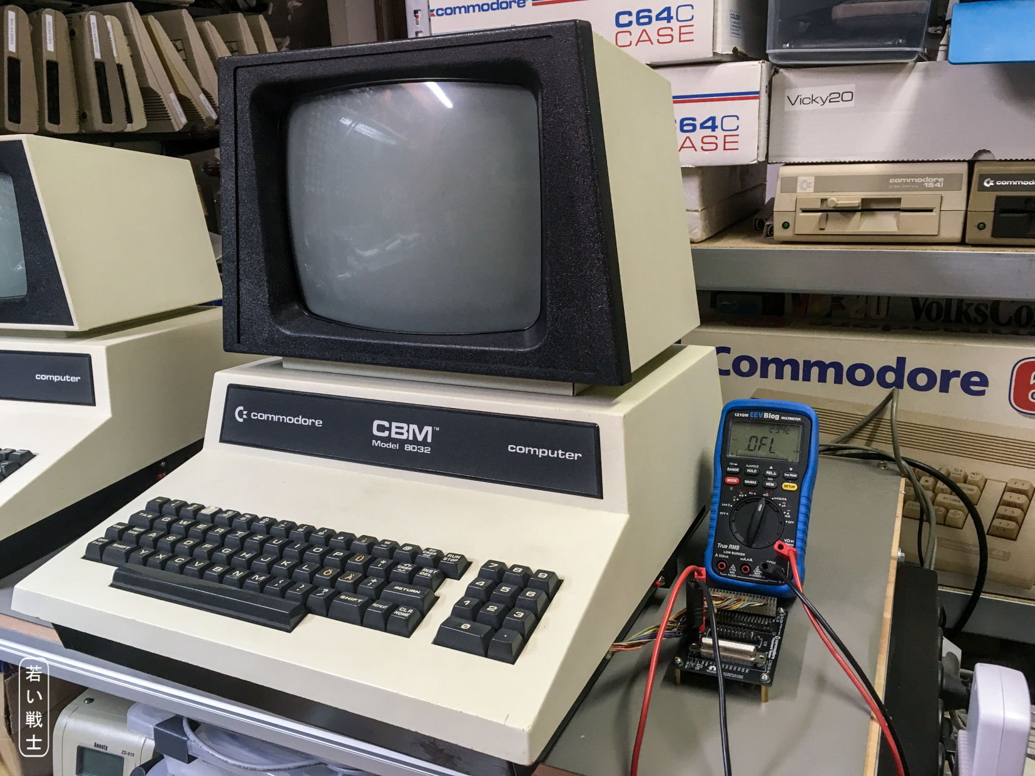
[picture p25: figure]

Figure 4: Testing the CBM8032 keyboard

Every key produced a reading which was within the range.

## 2.5. C16

After connecting the keyboard, the meter showed OFL.

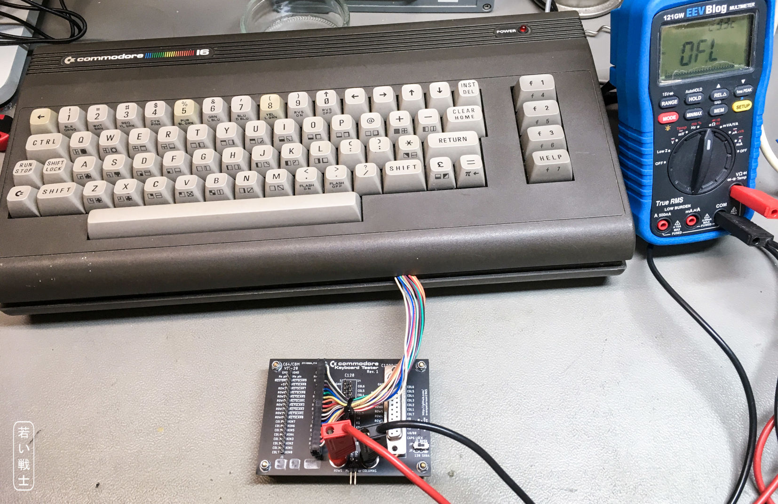
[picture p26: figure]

Figure 5: Testing the C16 keyboard

Every key produced a reading which was within the range.

## 2.6. C128

After connecting the keyboard, the meter showed OFL.

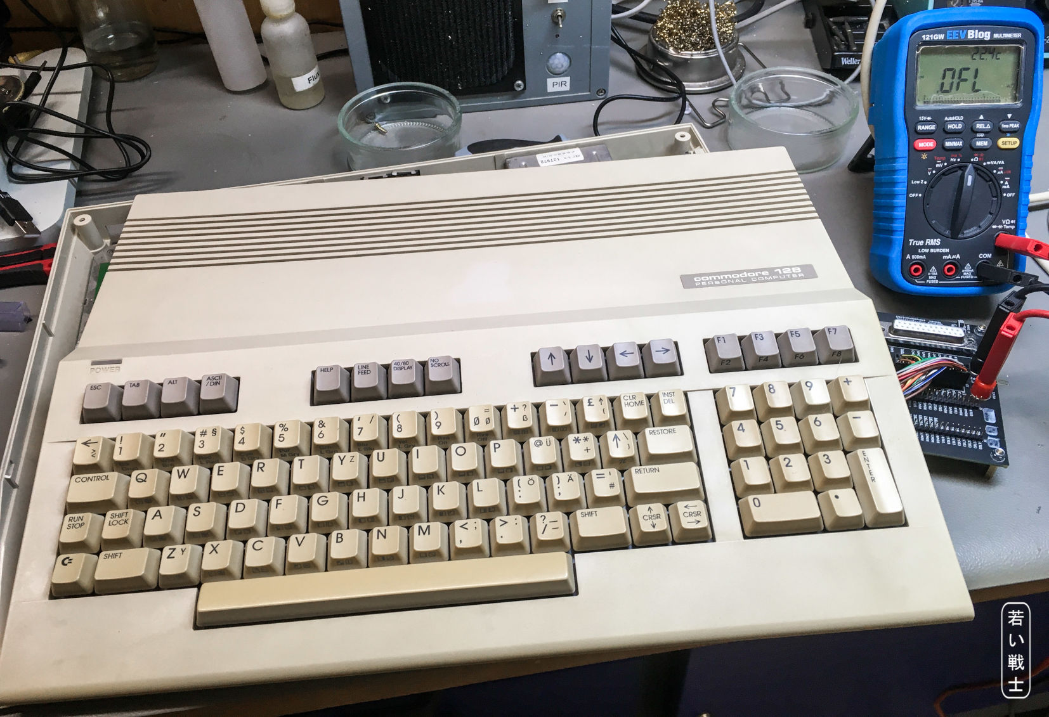
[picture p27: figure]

Figure 6: Testing the C128 keyboard

Every key produced a reading which was within the range.

## 2.7. C128D

After connecting the keyboard, the meter showed OFL.

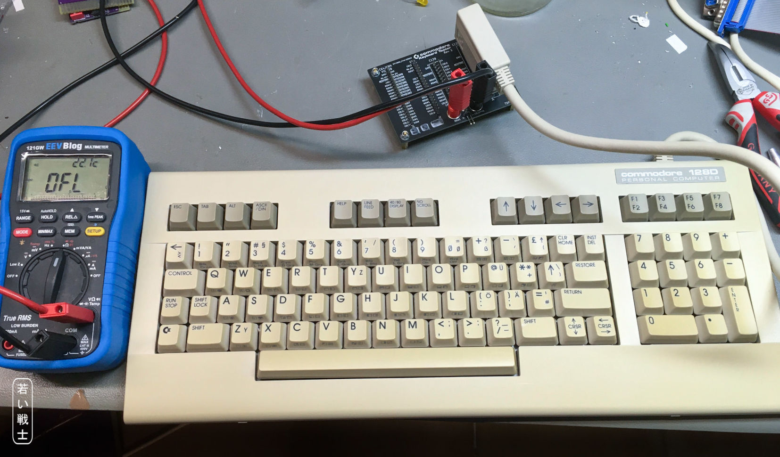
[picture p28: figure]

Figure 7: Testing the C128D keyboard

Every key produced a reading which was within the range.

## 2.8. SX-64

This required the ribbon cable (Drawing No. 188-3-01-01).

After connecting the keyboard, the meter showed OFL.

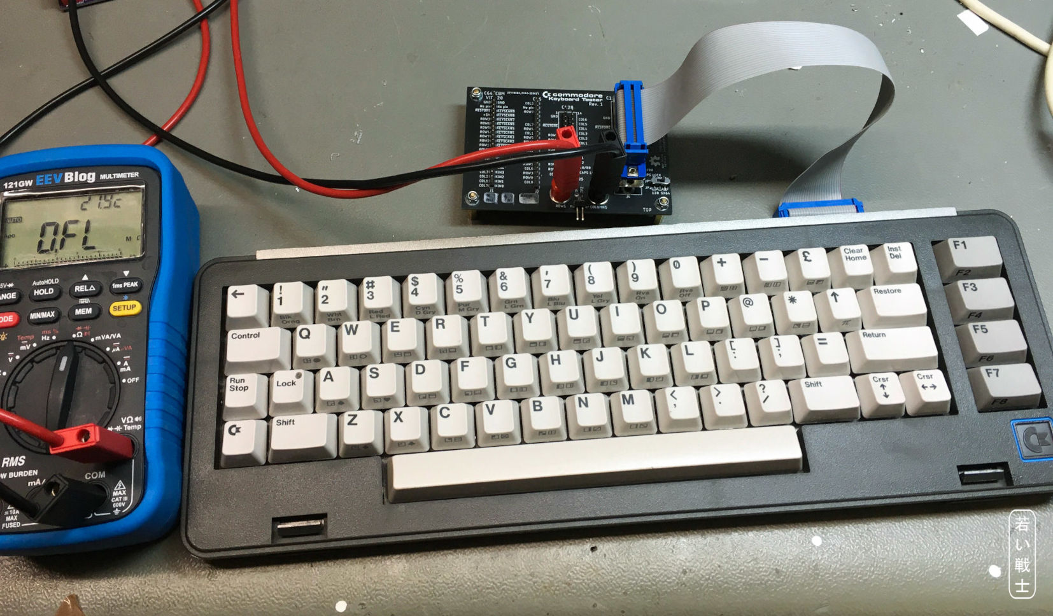
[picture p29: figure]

Figure 8: Testing the SX-64 keyboard

Every key produced a reading which was within the range.

# 3. Testing of Rev. 2

Rev. 2 was assembled and tested with a VIC-20 keyboard. It was functional. Since the circuit was not changed, further tests were not considered to be required.

# 4. Conclusion

The Commodore Keyboard Tester Rev. 1 is fully functional.

(Note: Rev. 0 was functional, except the SX-64 keyboard)

C=_KBTst_Testing.docx 28.05.2023 14:02 Drafted by Sven Petersen Page 2 of 2 Doc.-No.: 188-6-02-02

C=_KBTst_Testing.docx 28.05.2023 14:02 Drafted by Sven Petersen Page 1 of 1 Doc.-No.: 188-6-01-01

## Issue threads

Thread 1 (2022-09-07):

C128 Header - Feeling the pain :)

GeekNathan, 2022-09-07:
I tried inserting pins into my C128 keyboard connector but the receptacle pins are a little loose and after trying several times I could not get them all straight enough to insert fully. So I switched to doing one row which worked, but getting the second row in has been really difficult.

I rummaged through some old stuff to dig out my Keyrah (circa 2010). It does have a C128 header on it so not sure where they sourced theirs from.

So not so much an issue, but yeah, the C128 header is a PITA hehe.

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

svenpetersen1965, 2022-09-07:
Johan Grip told me, that cutting up a PCB type male DSUB-25 and soldering in upside down. He has made this C128 replica board. I have not tried it out, yet.
-cu Sven

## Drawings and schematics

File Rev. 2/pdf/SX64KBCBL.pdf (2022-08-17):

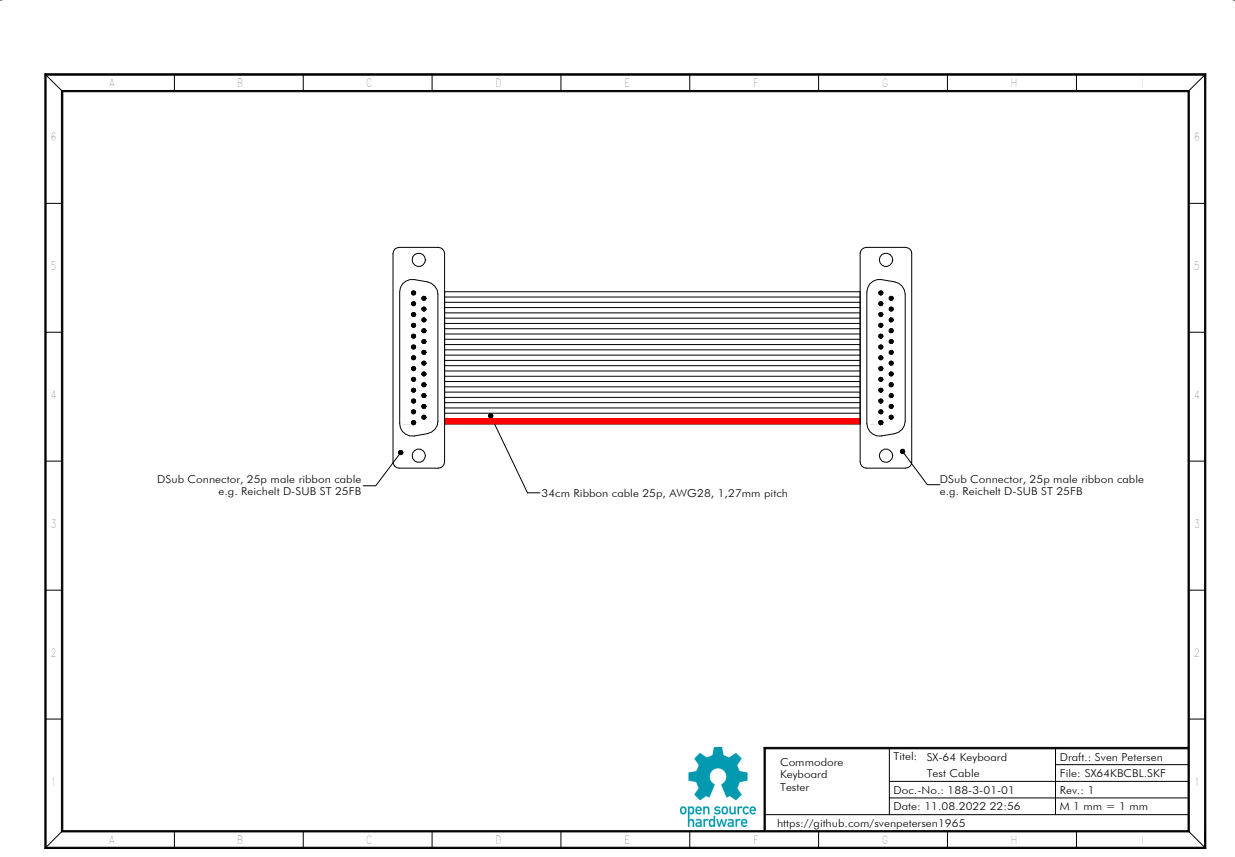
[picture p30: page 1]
SX-64 Keyboard; Test Cable; File:; Titel:; Doc.-No.: 188-3-01-01; Date: 11.08.2022 22:56; Commodore Keyboard Tester

DSub Connector, 25p male ribbon cable

e.g. Reichelt D-SUB ST 25FB

34cm Ribbon cable 25p, AWG28, 1,27mm pitch

Draft.: Sven Petersen
SX64KBCBL.SKF
Rev.: 1

https://github.com/svenpetersen1965

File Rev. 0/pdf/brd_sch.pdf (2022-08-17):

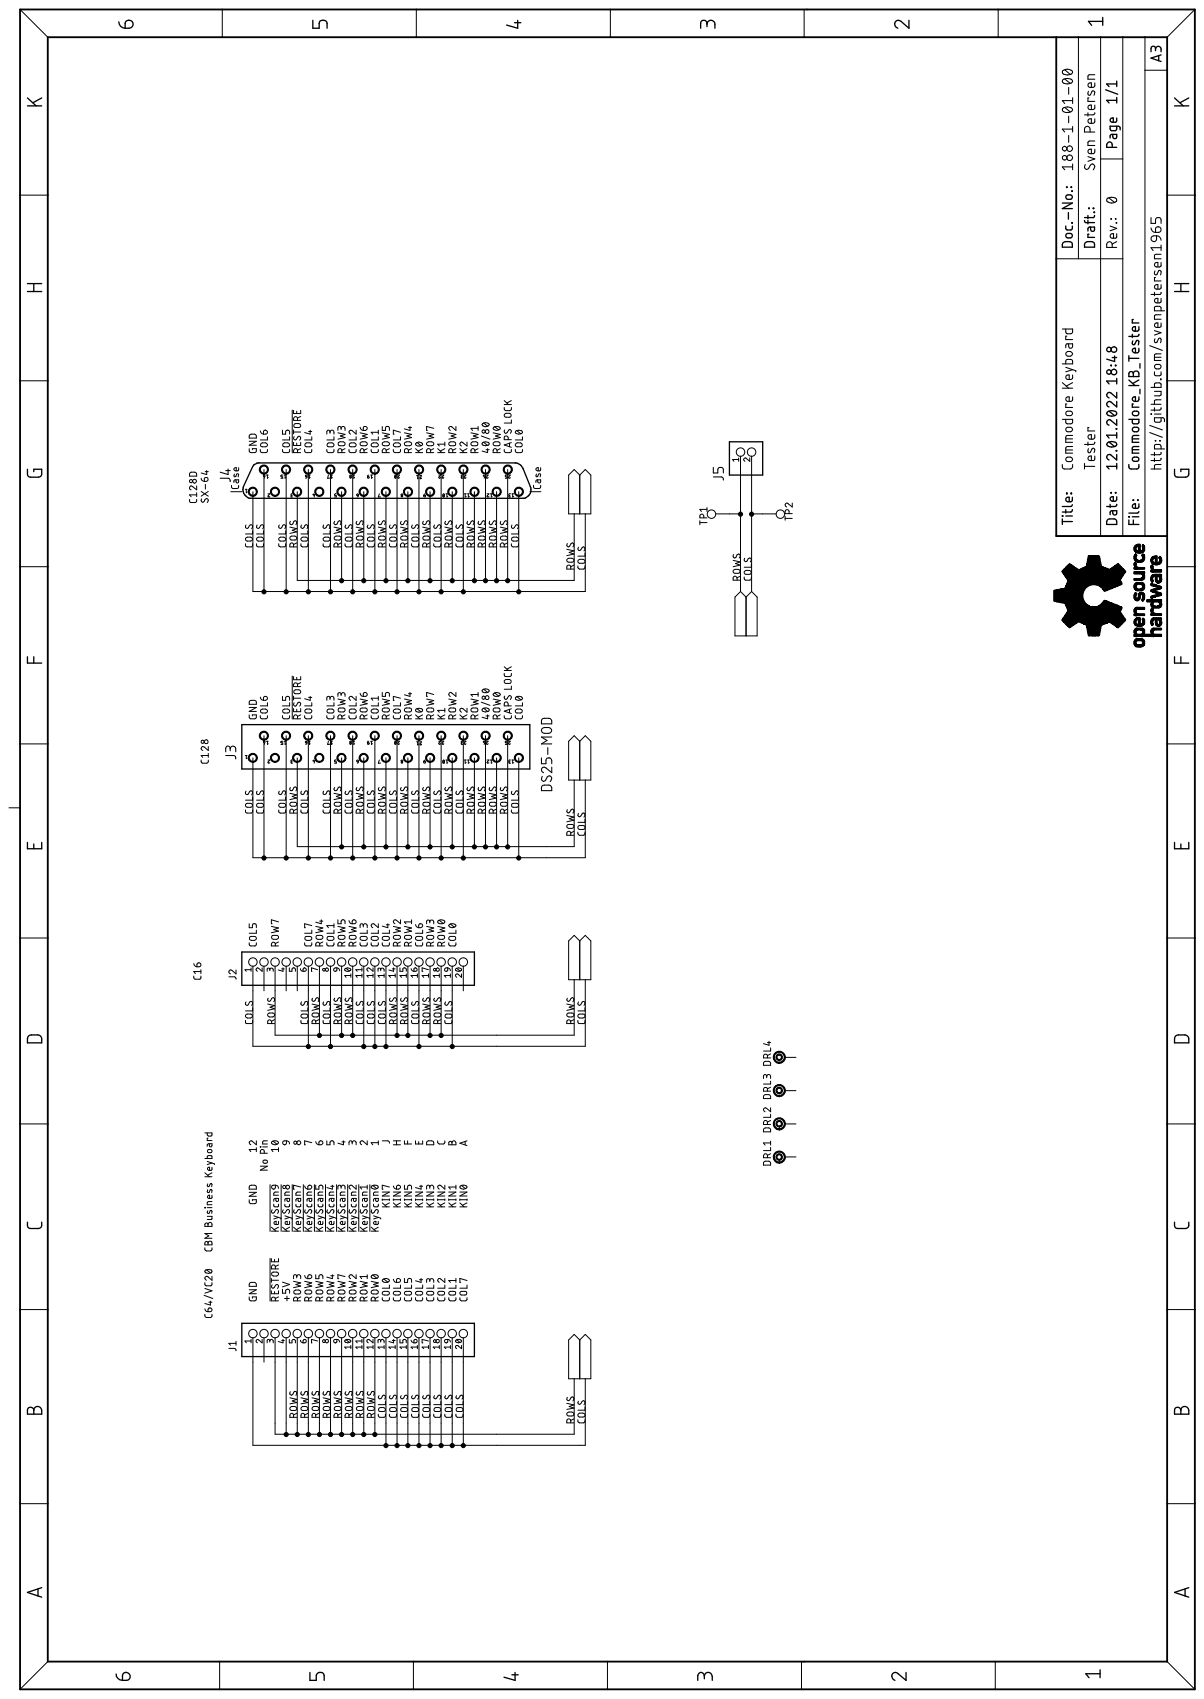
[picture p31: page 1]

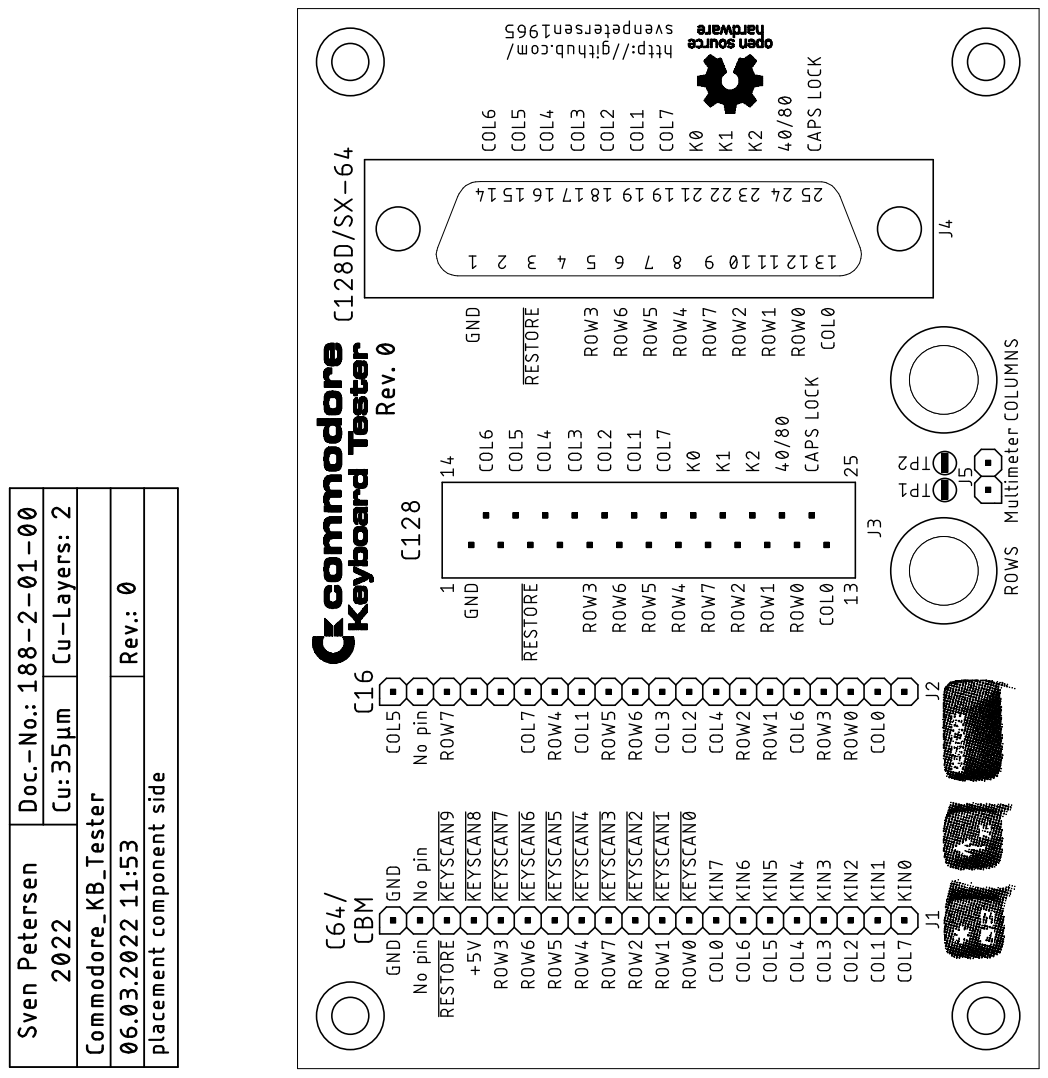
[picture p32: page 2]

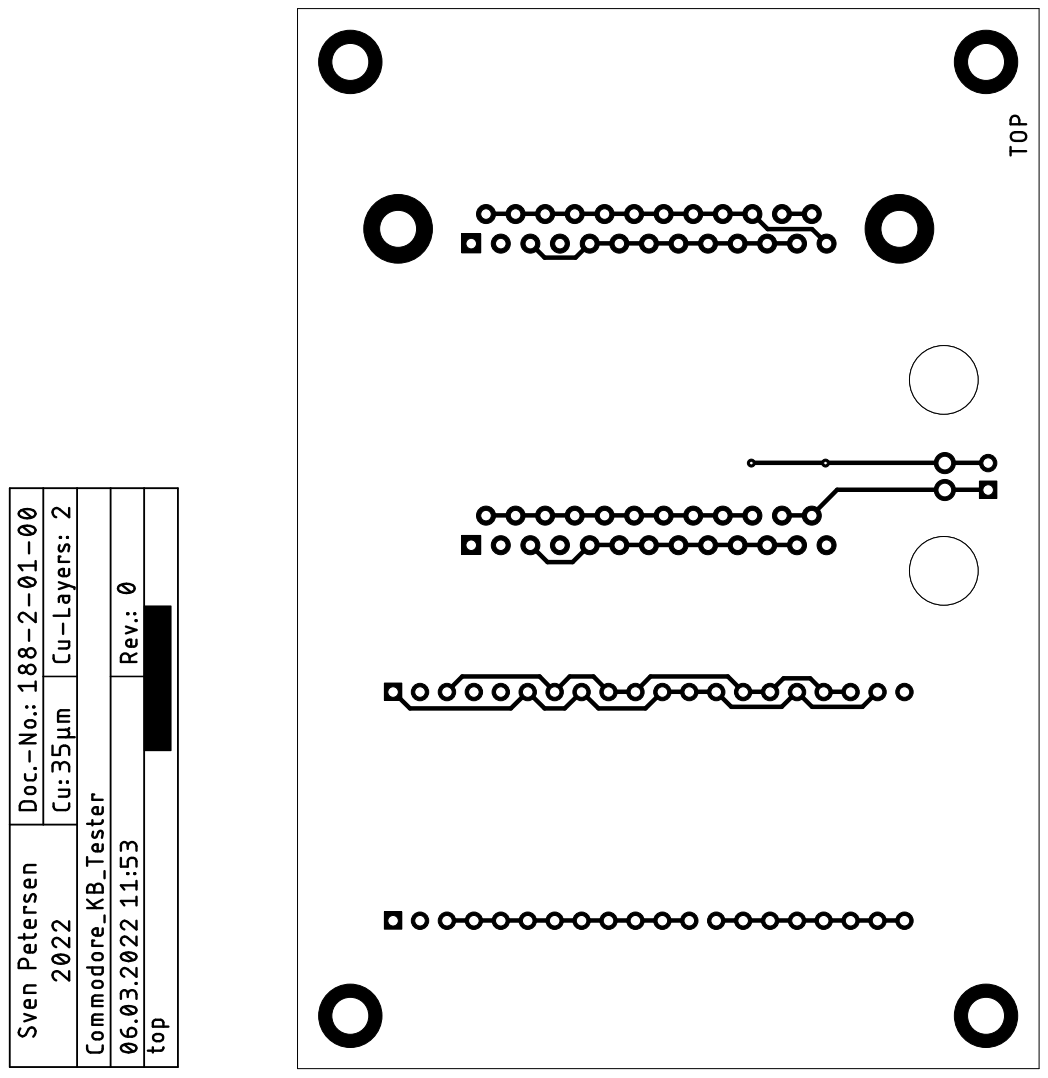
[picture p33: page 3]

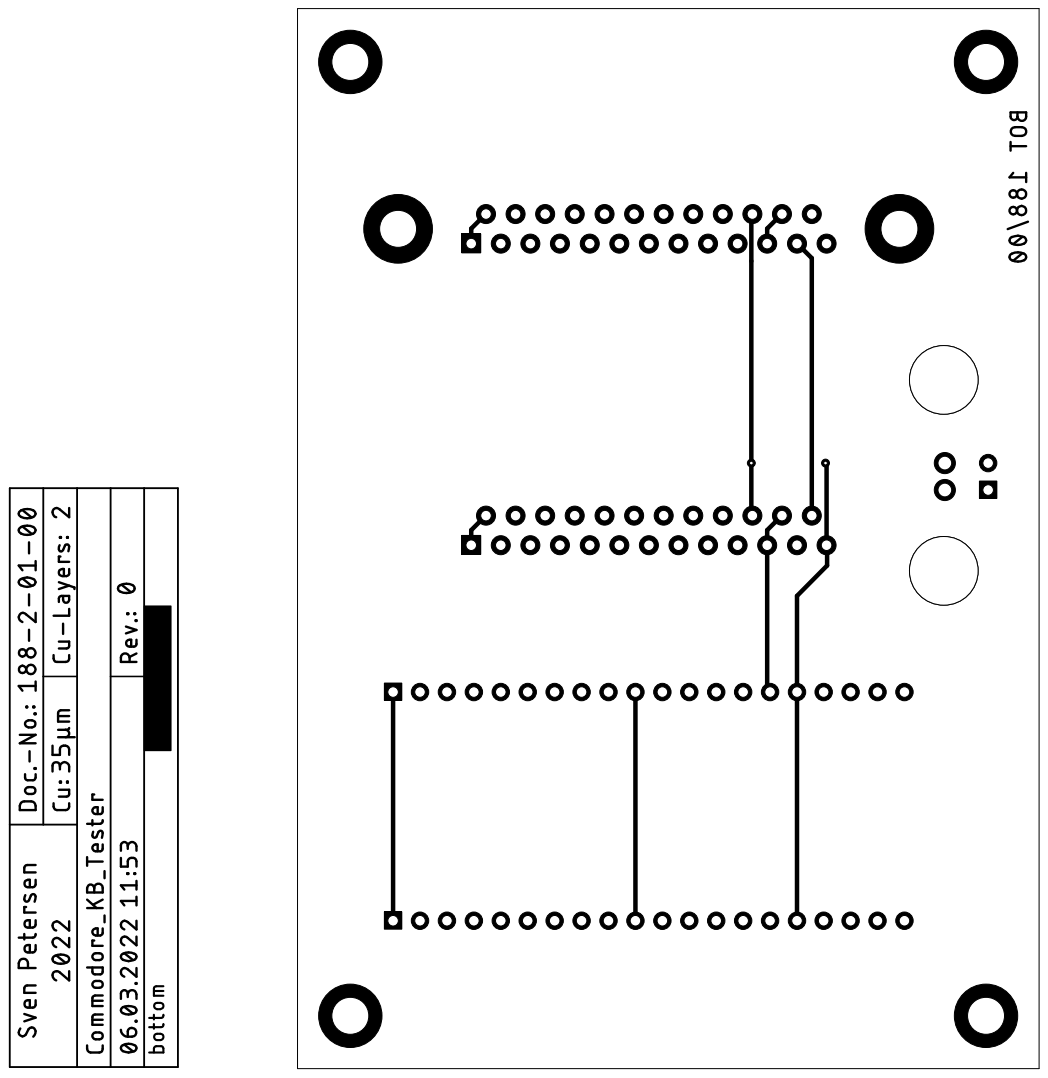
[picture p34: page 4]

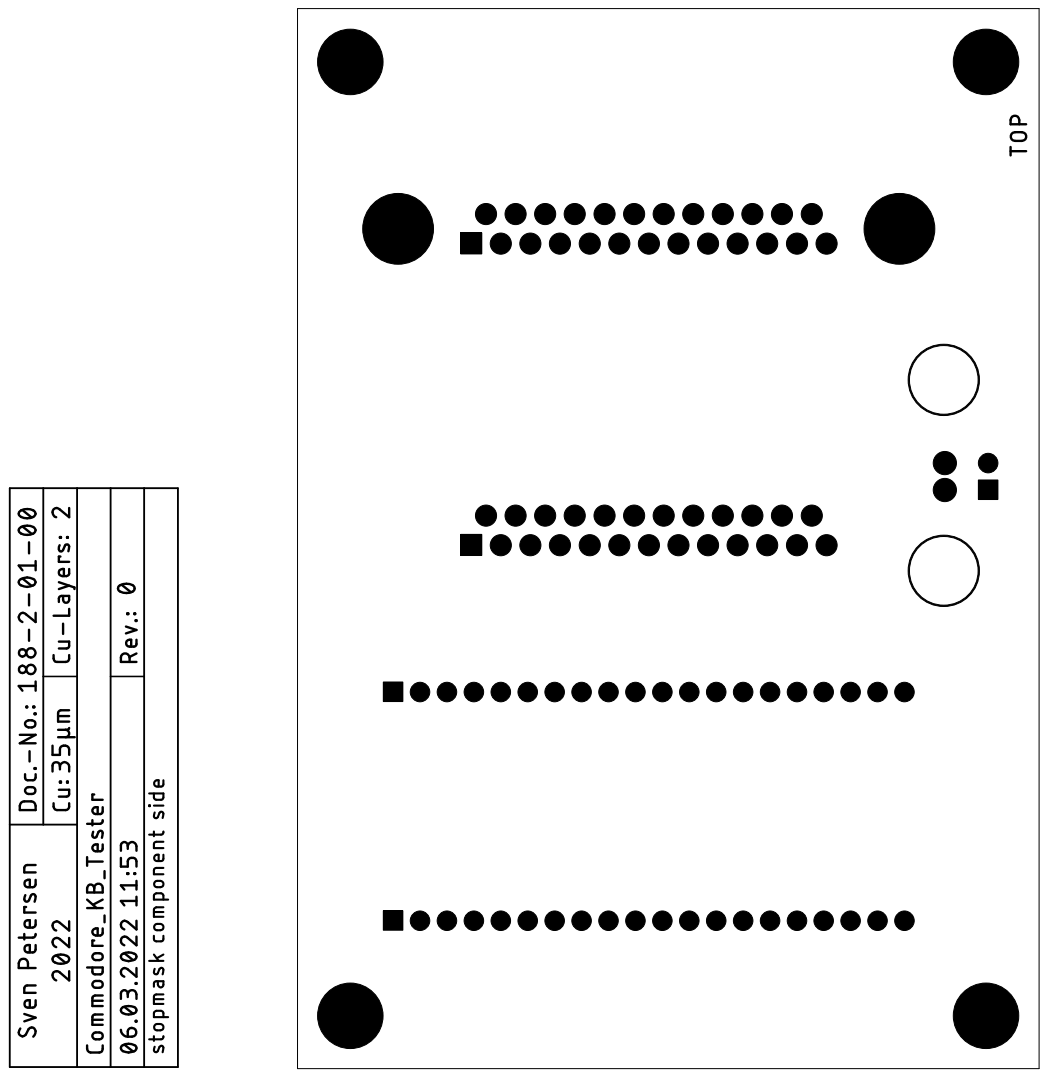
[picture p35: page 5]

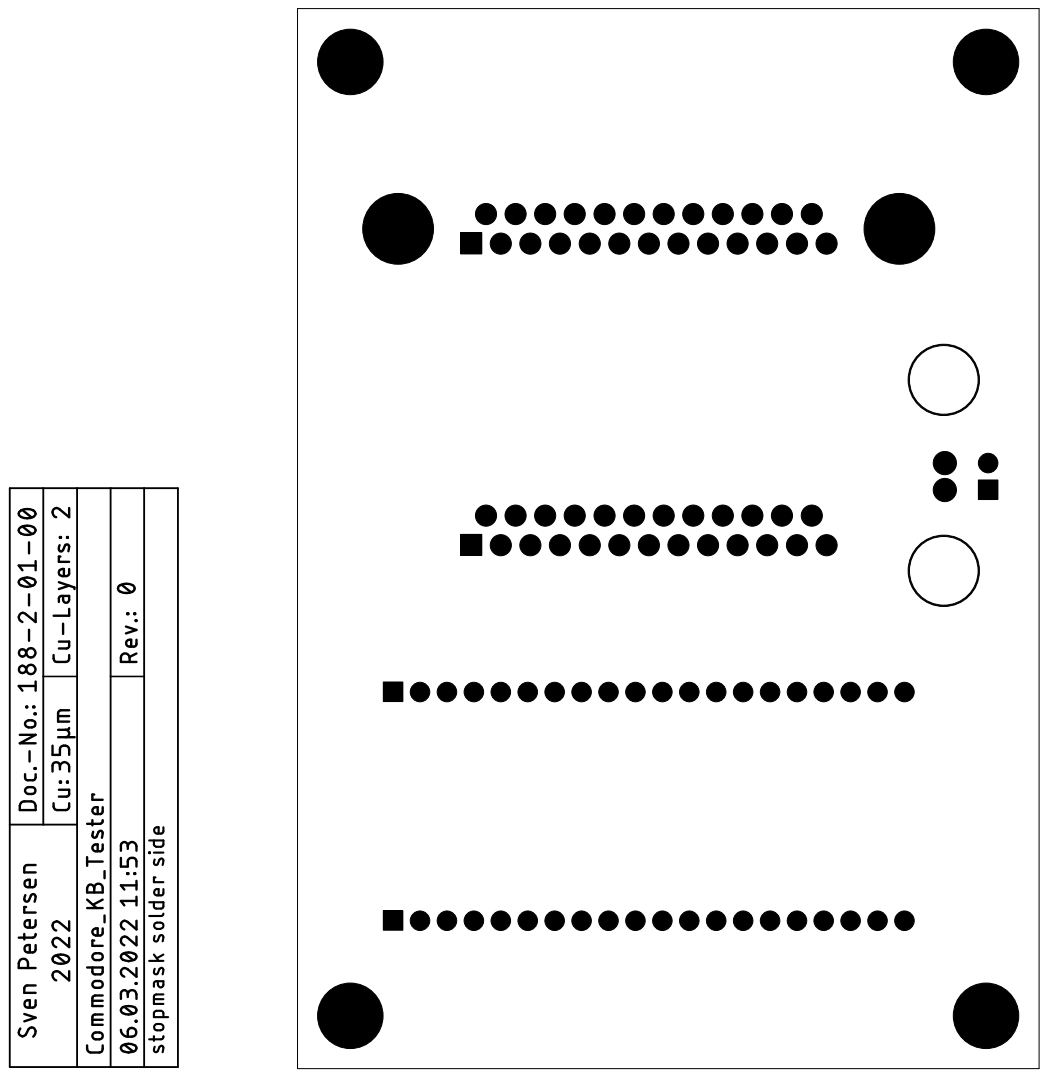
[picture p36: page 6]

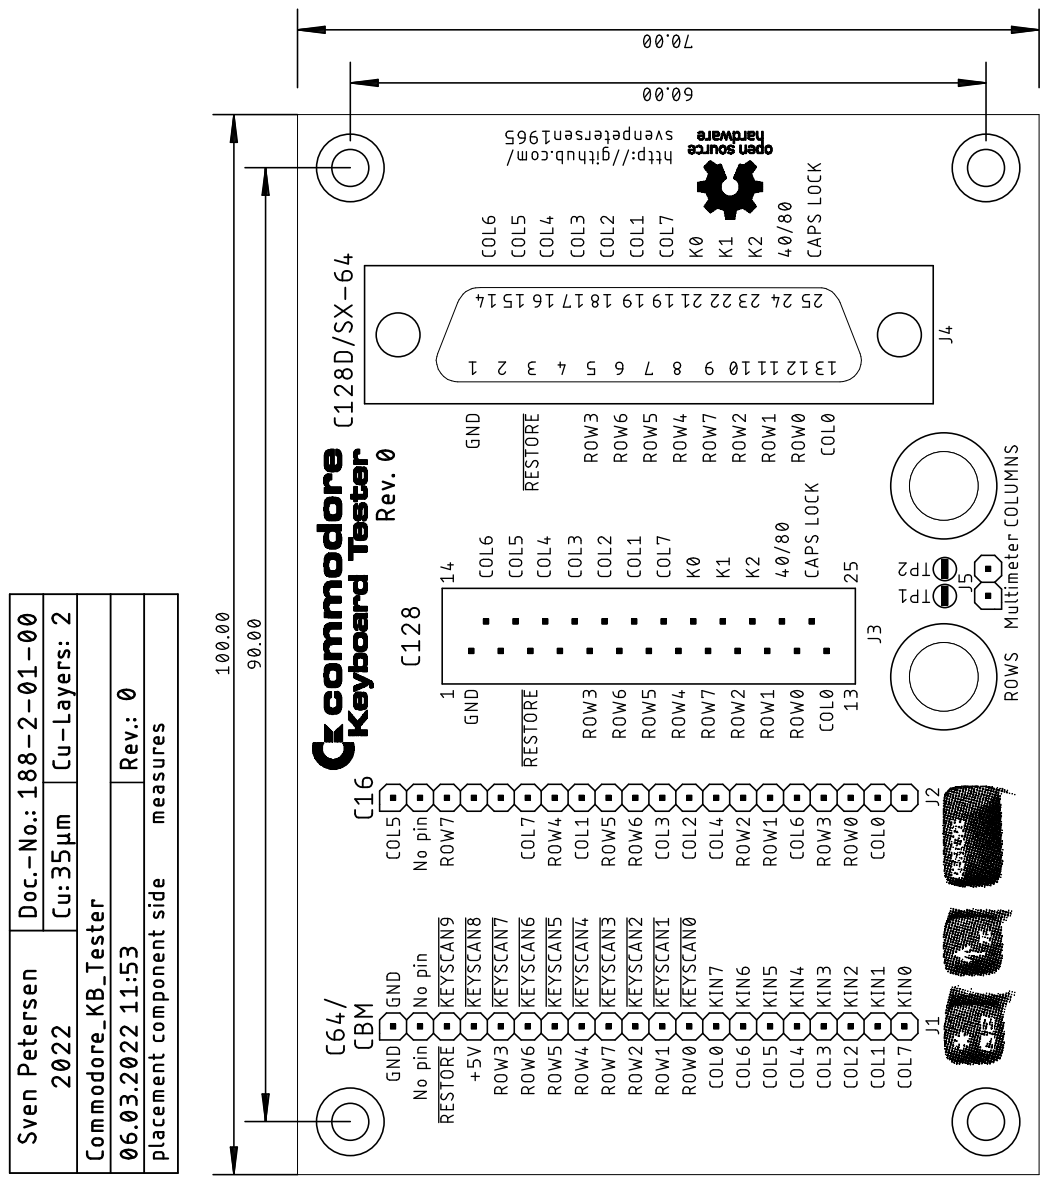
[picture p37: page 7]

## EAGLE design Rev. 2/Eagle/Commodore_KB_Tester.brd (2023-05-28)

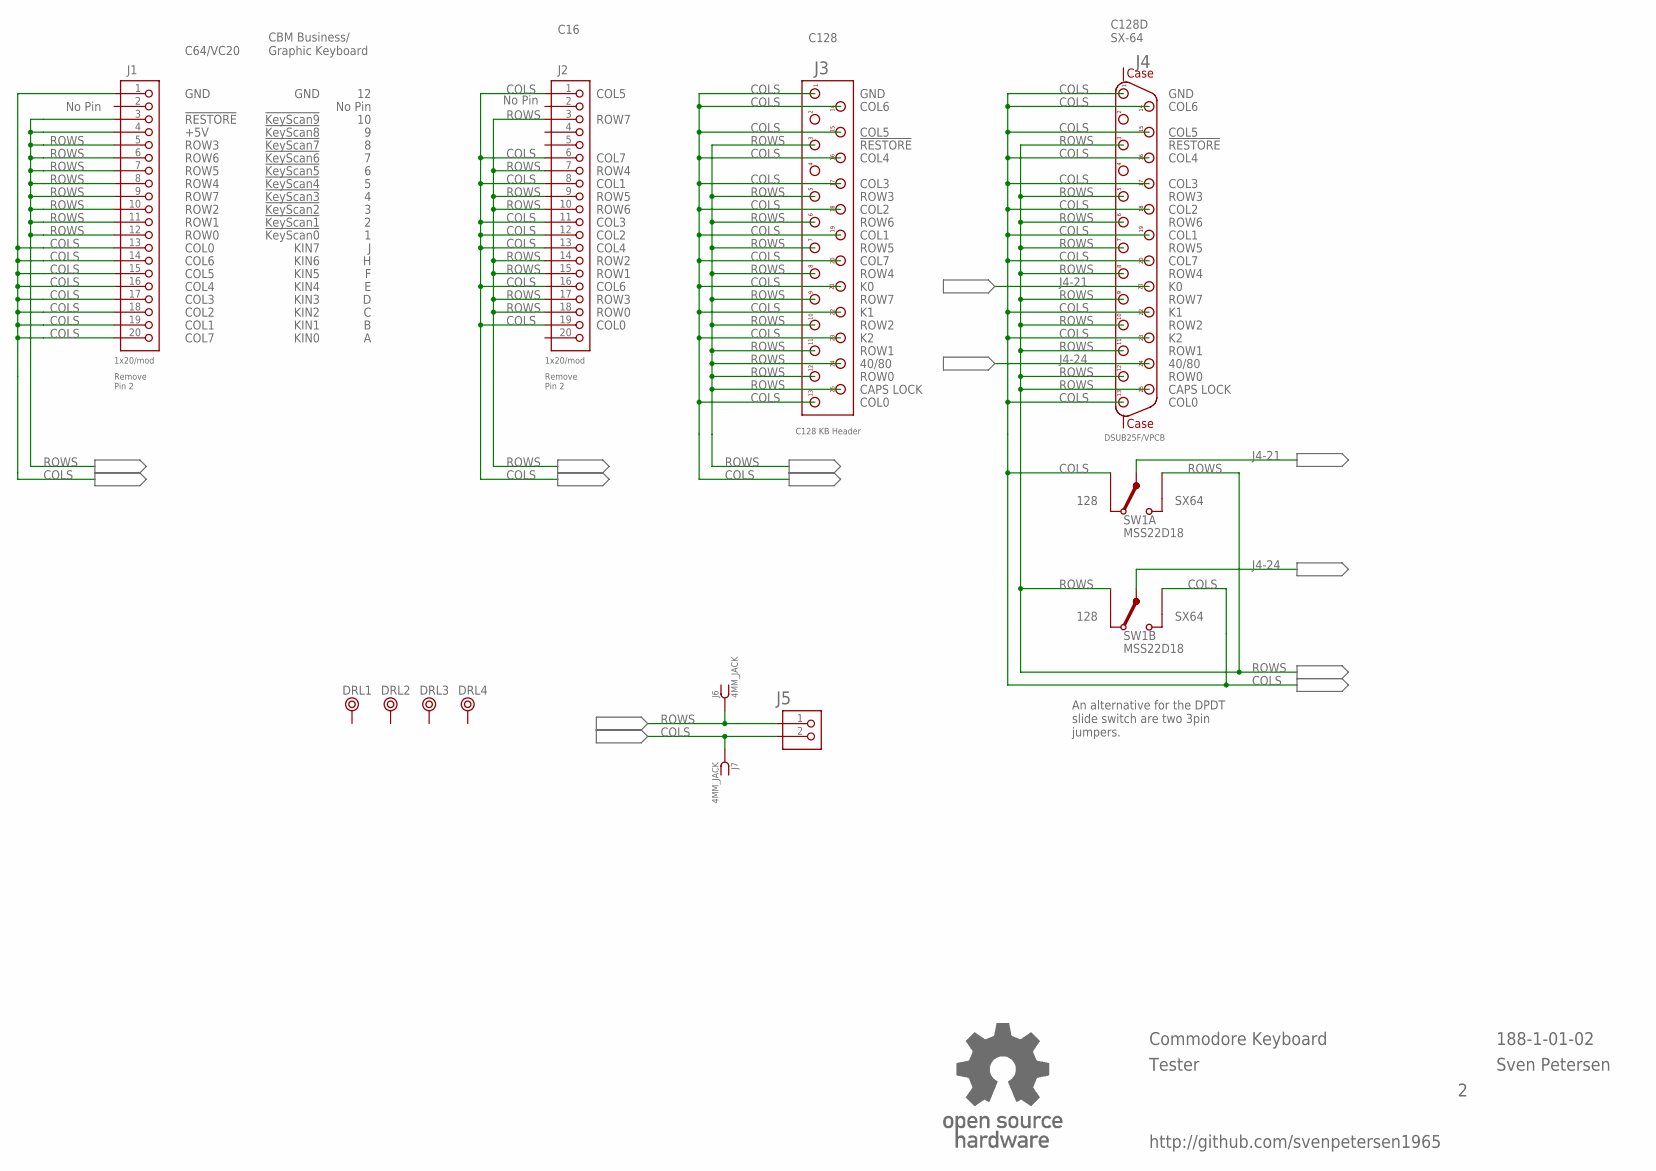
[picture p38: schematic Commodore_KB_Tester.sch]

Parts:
DRL1, DRL2, DRL3, DRL4: BOHR3,5
J1, J2: 1x20/mod; 1X20
J3: C128 KB Header; C128KB_HEADER
J4: DSUB25F/VPCB; DS25F-V
J5: PINHD-1X2; 1X02
J6, J7: 4MM_JACK; JACK4MM
SW1: MSS22D18; DPDT_9MM
U$12: OPEN_SOURCE_HW; OPENHW

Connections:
COLS: J1.1, J1.13, J1.14, J1.15, J1.16, J1.17, J1.18, J1.19, J1.20, J2.1, J2.6, J2.8, J2.11, J2.12, J2.13, J2.16, J2.19, J3.1, J3.13, J3.14, J3.15, J3.16, J3.17, J3.18, J3.19, J3.20, J3.21, J3.22, J3.23, J4.1, J4.13, J4.14, J4.15, J4.16, J4.17, J4.18, J4.19, J4.20, J4.22, J4.23, J5.2, J7.1, J7.1A, SW1.3 (DWN), SW1.6 (UP)
J4-21: J4.21, SW1.2 (COM)
J4-24: J4.24, SW1.5 (COM)
ROWS: J1.3, J1.4, J1.5, J1.6, J1.7, J1.8, J1.9, J1.10, J1.11, J1.12, J2.3, J2.7, J2.9, J2.10, J2.14, J2.15, J2.17, J2.18, J3.3, J3.5, J3.6, J3.7, J3.8, J3.9, J3.10, J3.11, J3.12, J3.24, J3.25, J4.3, J4.5, J4.6, J4.7, J4.8, J4.9, J4.10, J4.11, J4.12, J4.25, J5.1, J6.1, J6.1A, SW1.1 (UP), SW1.4 (DWN)

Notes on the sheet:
GND
!RESTORE
+5V
ROW3
ROW6
ROW5
ROW4
ROW7
ROW2
ROW1
ROW0
COL0
COL6
COL5
COL4
COL3
COL2
COL1
COL7
C64/VC20
No Pin
!KeyScan0
!KeyScan1
!KeyScan2
!KeyScan3
!KeyScan4
!KeyScan5
!KeyScan6
!KeyScan7
!KeyScan8
!KeyScan9
KIN0
KIN1
KIN2
KIN3
KIN4
KIN5
KIN6
KIN7
CBM Business/ Graphic Keyboard

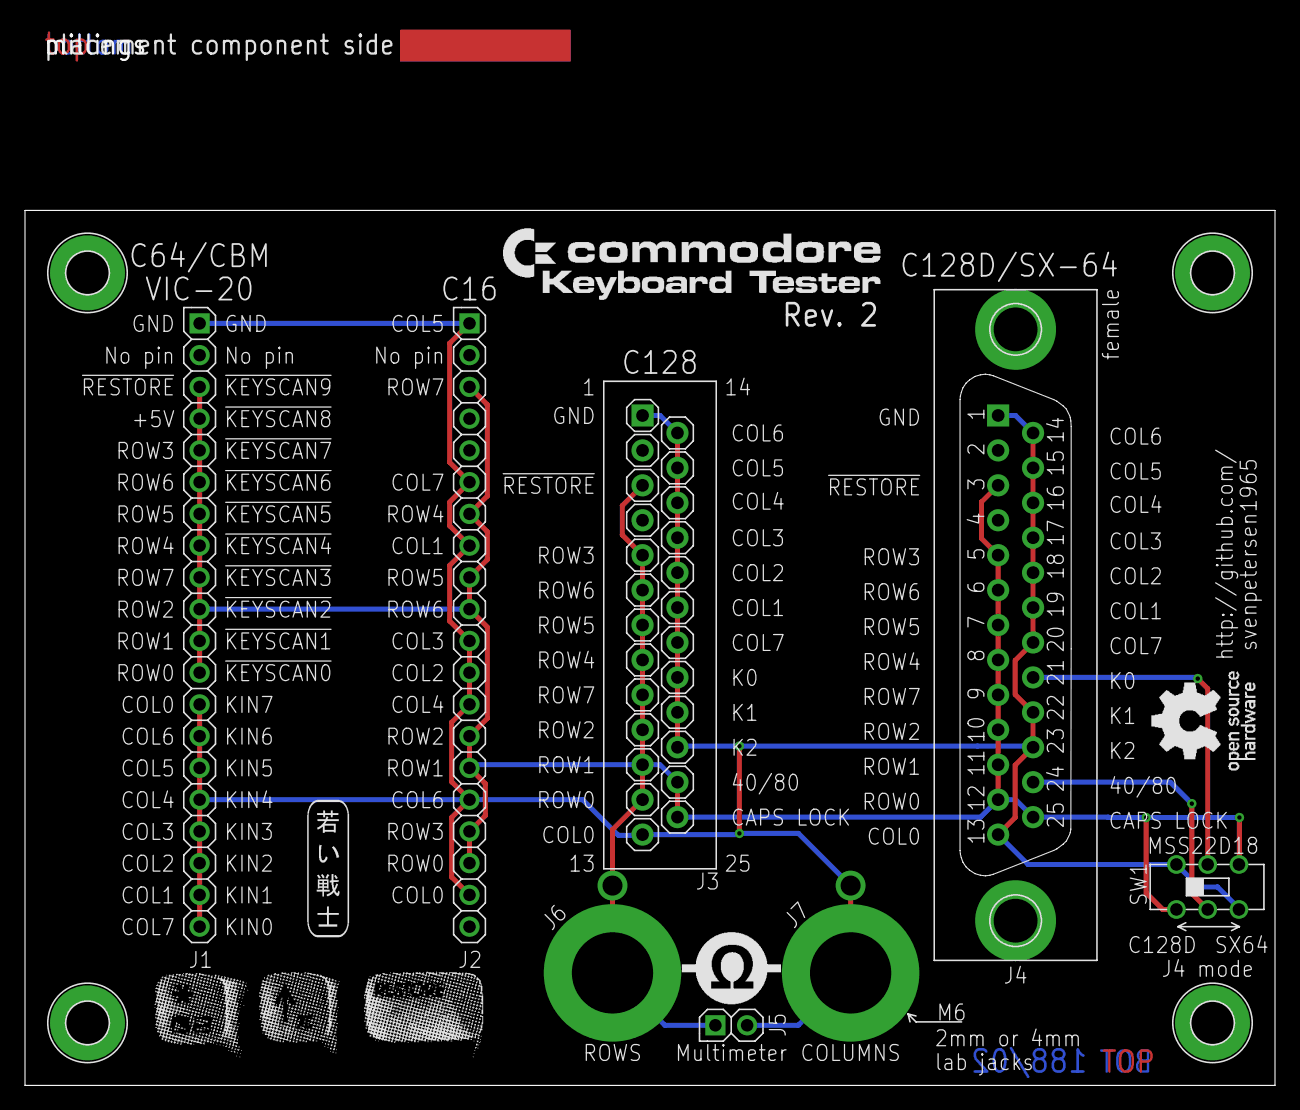
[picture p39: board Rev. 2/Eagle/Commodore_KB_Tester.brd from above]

Board: 2 copper layers, 100.0 x 70.0 mm, 19 parts (0 on the bottom side), 4 nets.

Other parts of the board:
U$13: C64_KEYS
U$14: 2LAYER
U$15: PCB-TITLE/
U$16: COMMODORE_KB
U$21: SVEN_TAG
U$22: OHMMETER

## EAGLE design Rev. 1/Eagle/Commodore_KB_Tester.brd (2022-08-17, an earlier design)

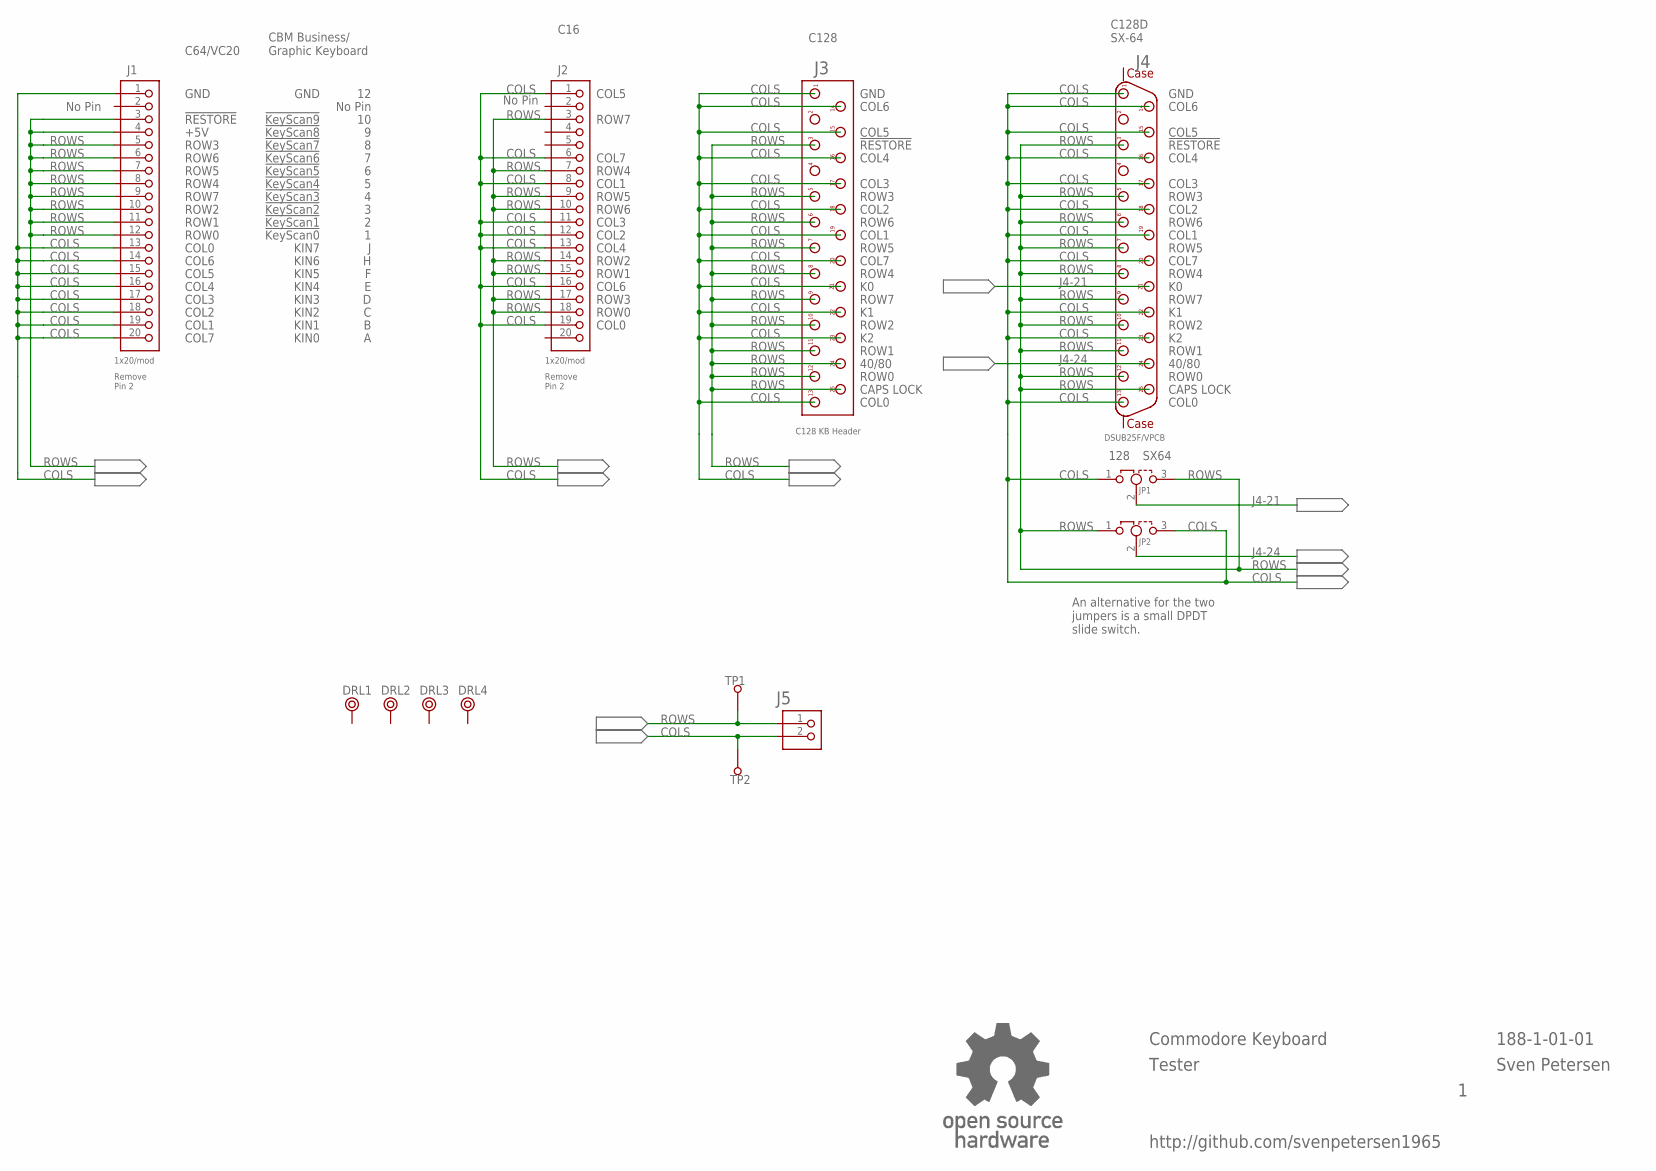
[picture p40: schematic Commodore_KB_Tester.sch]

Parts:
DRL1, DRL2, DRL3, DRL4: BOHR3,5
J1, J2: 1x20/mod; 1X20
J3: C128 KB Header; C128KB_HEADER
J4: DSUB25F/VPCB; DS25F-V
J5: PINHD-1X2; 1X02
JP1, JP2: DJUMPER; 1X03
TP1, TP2: 1,3/2,0
U$12: OPEN_SOURCE_HW; OPENHW

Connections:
COLS: J1.1, J1.13, J1.14, J1.15, J1.16, J1.17, J1.18, J1.19, J1.20, J2.1, J2.6, J2.8, J2.11, J2.12, J2.13, J2.16, J2.19, J3.1, J3.13, J3.14, J3.15, J3.16, J3.17, J3.18, J3.19, J3.20, J3.21, J3.22, J3.23, J4.1, J4.13, J4.14, J4.15, J4.16, J4.17, J4.18, J4.19, J4.20, J4.22, J4.23, J5.2, JP1.1, JP2.3, TP2.1
J4-21: J4.21, JP1.2
J4-24: J4.24, JP2.2
ROWS: J1.3, J1.4, J1.5, J1.6, J1.7, J1.8, J1.9, J1.10, J1.11, J1.12, J2.3, J2.7, J2.9, J2.10, J2.14, J2.15, J2.17, J2.18, J3.3, J3.5, J3.6, J3.7, J3.8, J3.9, J3.10, J3.11, J3.12, J3.24, J3.25, J4.3, J4.5, J4.6, J4.7, J4.8, J4.9, J4.10, J4.11, J4.12, J4.25, J5.1, JP1.3, JP2.1, TP1.1

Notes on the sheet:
GND
!RESTORE
+5V
ROW3
ROW6
ROW5
ROW4
ROW7
ROW2
ROW1
ROW0
COL0
COL6
COL5
COL4
COL3
COL2
COL1
COL7
C64/VC20
No Pin
!KeyScan0
!KeyScan1
!KeyScan2
!KeyScan3
!KeyScan4
!KeyScan5
!KeyScan6
!KeyScan7
!KeyScan8
!KeyScan9
KIN0
KIN1
KIN2
KIN3
KIN4
KIN5
KIN6
KIN7
CBM Business/ Graphic Keyboard

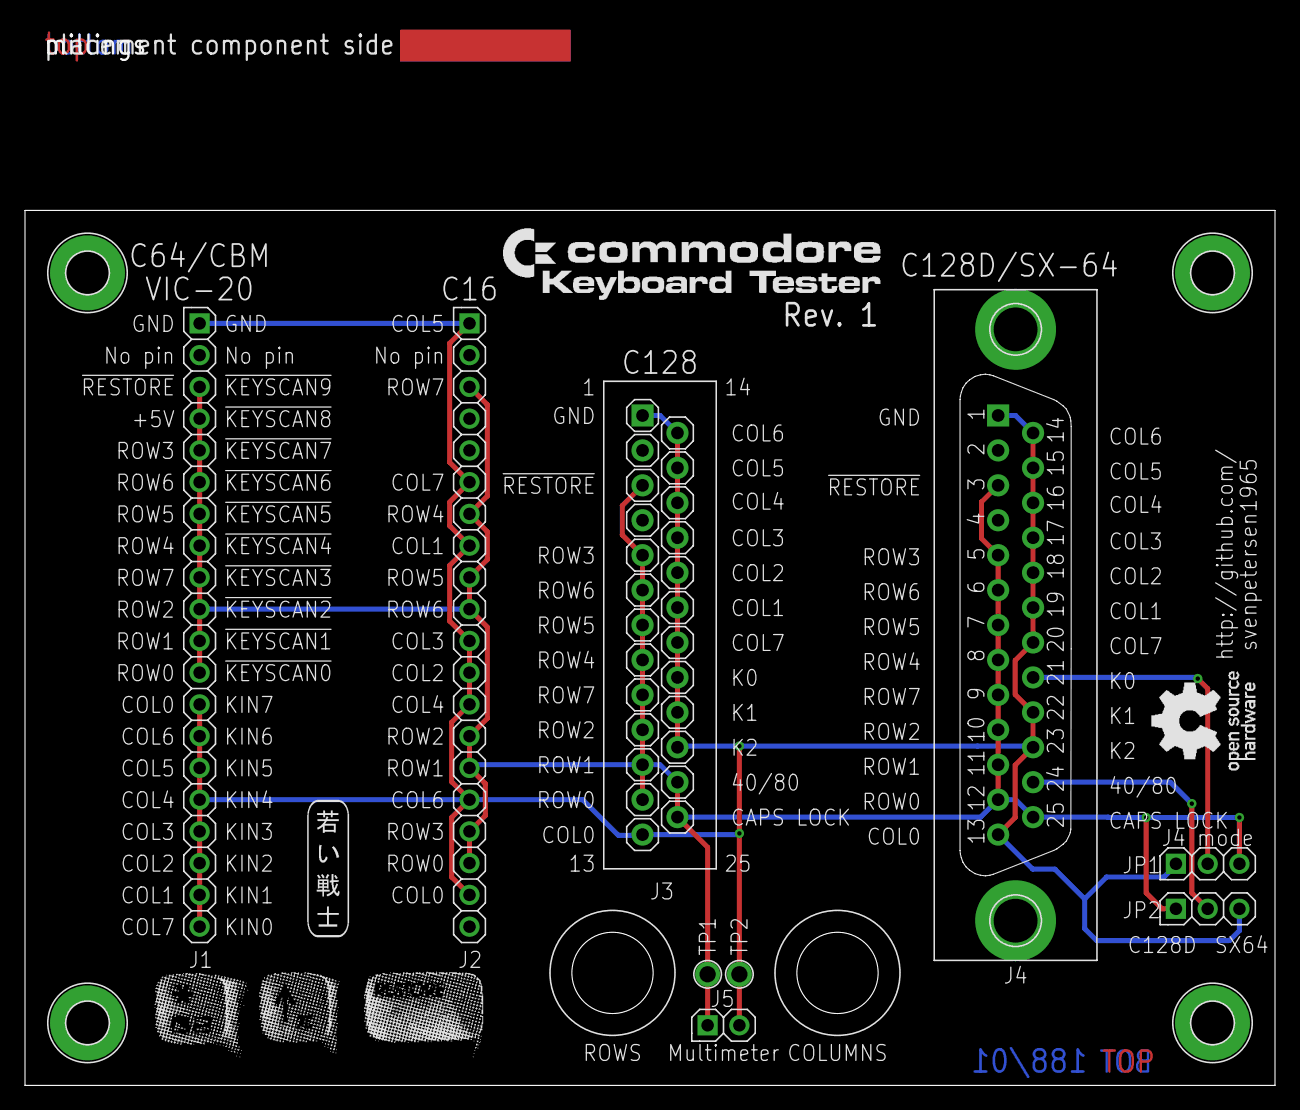
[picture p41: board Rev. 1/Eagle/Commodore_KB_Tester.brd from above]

Board: 2 copper layers, 100.0 x 70.0 mm, 19 parts (0 on the bottom side), 4 nets.

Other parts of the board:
U$13: C64_KEYS
U$14: 2LAYER
U$15: PCB-TITLE/
U$16: COMMODORE_KB
U$21: SVEN_TAG

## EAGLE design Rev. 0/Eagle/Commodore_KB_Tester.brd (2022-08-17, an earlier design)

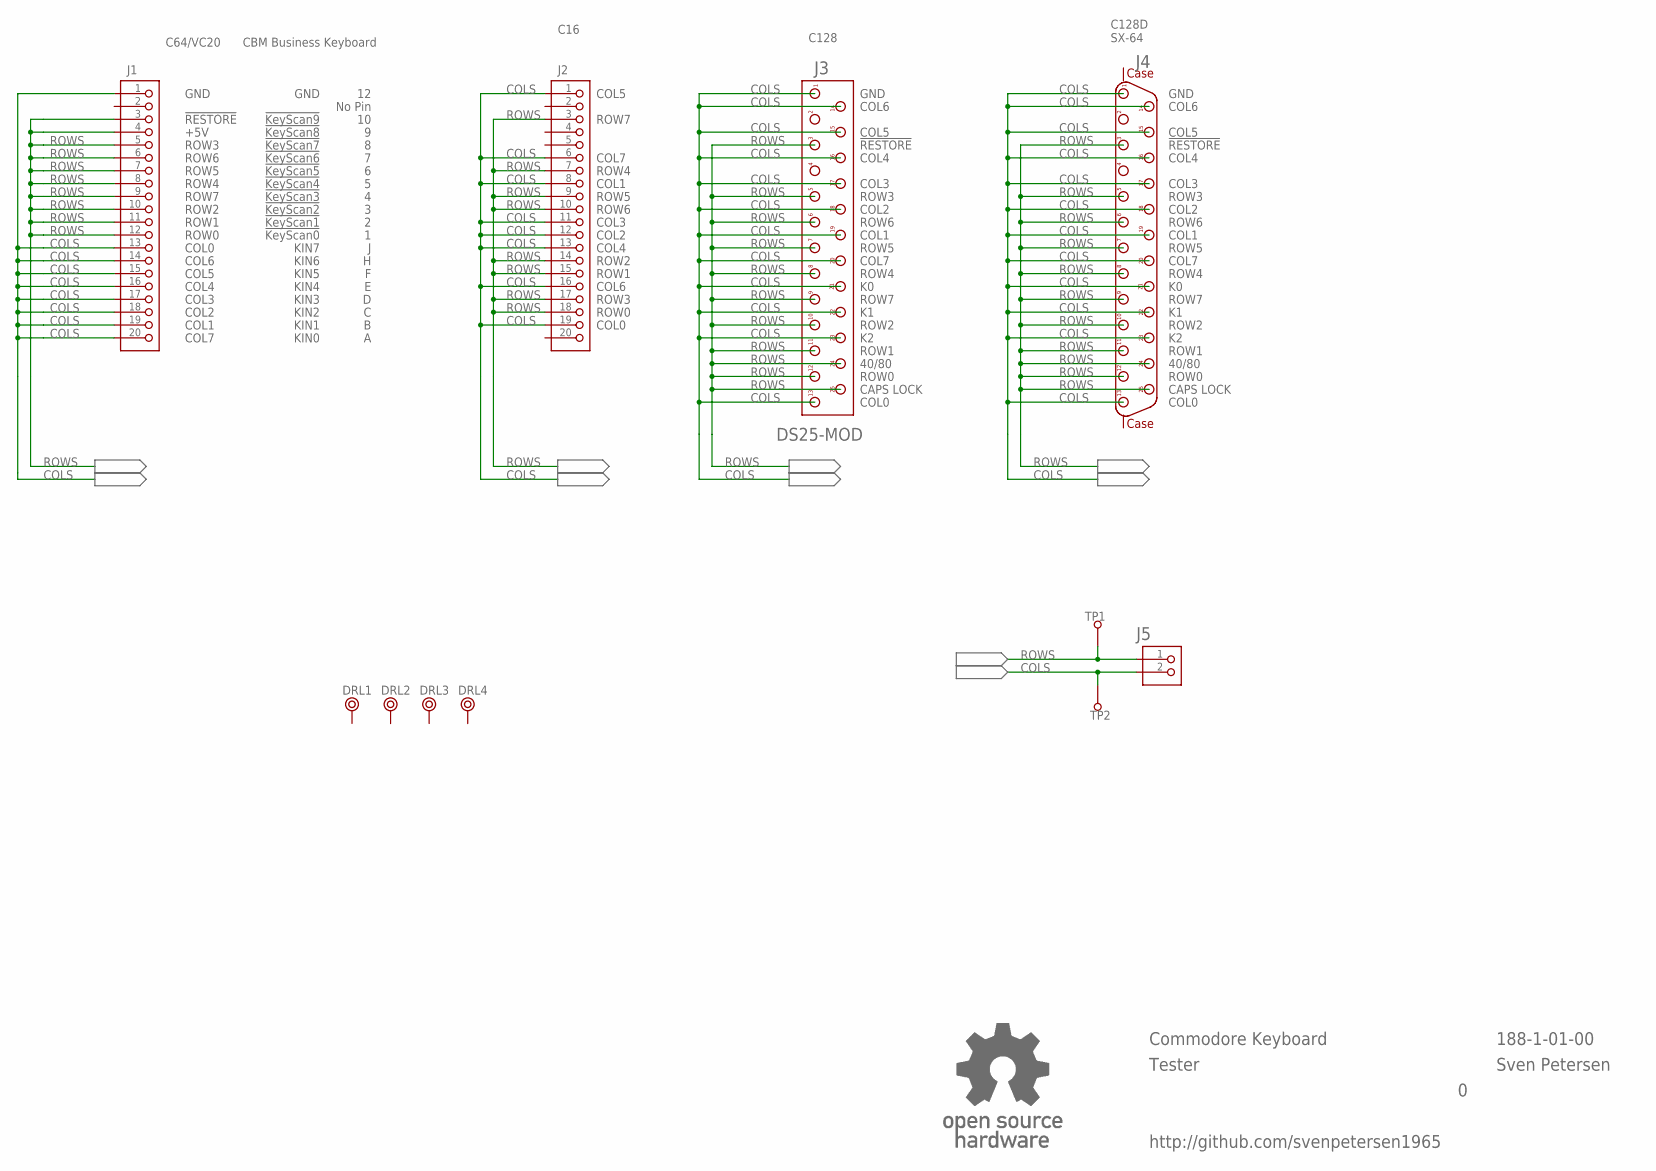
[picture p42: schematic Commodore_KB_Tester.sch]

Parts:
DRL1, DRL2, DRL3, DRL4: BOHR3,5
J1, J2: PINHD-1X20; 1X20
J3: DS25-MOD; C128KB_HEADER
J4: DS25F-V-CL; DS25F-V
J5: PINHD-1X2; 1X02
TP1, TP2: 1,3/2,0
U$12: OPEN_SOURCE_HW; OPENHW

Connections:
COLS: J1.1, J1.13, J1.14, J1.15, J1.16, J1.17, J1.18, J1.19, J1.20, J2.1, J2.6, J2.8, J2.11, J2.12, J2.13, J2.16, J2.19, J3.1, J3.13, J3.14, J3.15, J3.16, J3.17, J3.18, J3.19, J3.20, J3.21, J3.22, J3.23, J4.1, J4.13, J4.14, J4.15, J4.16, J4.17, J4.18, J4.19, J4.20, J4.21, J4.22, J4.23, J5.2, TP2.1
ROWS: J1.3, J1.4, J1.5, J1.6, J1.7, J1.8, J1.9, J1.10, J1.11, J1.12, J2.3, J2.7, J2.9, J2.10, J2.14, J2.15, J2.17, J2.18, J3.3, J3.5, J3.6, J3.7, J3.8, J3.9, J3.10, J3.11, J3.12, J3.24, J3.25, J4.3, J4.5, J4.6, J4.7, J4.8, J4.9, J4.10, J4.11, J4.12, J4.24, J4.25, J5.1, TP1.1

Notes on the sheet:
GND
!RESTORE
+5V
ROW3
ROW6
ROW5
ROW4
ROW7
ROW2
ROW1
ROW0
COL0
COL6
COL5
COL4
COL3
COL2
COL1
COL7
C64/VC20
No Pin
!KeyScan0
!KeyScan1
!KeyScan2
!KeyScan3
!KeyScan4
!KeyScan5
!KeyScan6
!KeyScan7
!KeyScan8
!KeyScan9
KIN0
KIN1
KIN2
KIN3
KIN4
KIN5
KIN6
KIN7
CBM Business Keyboard

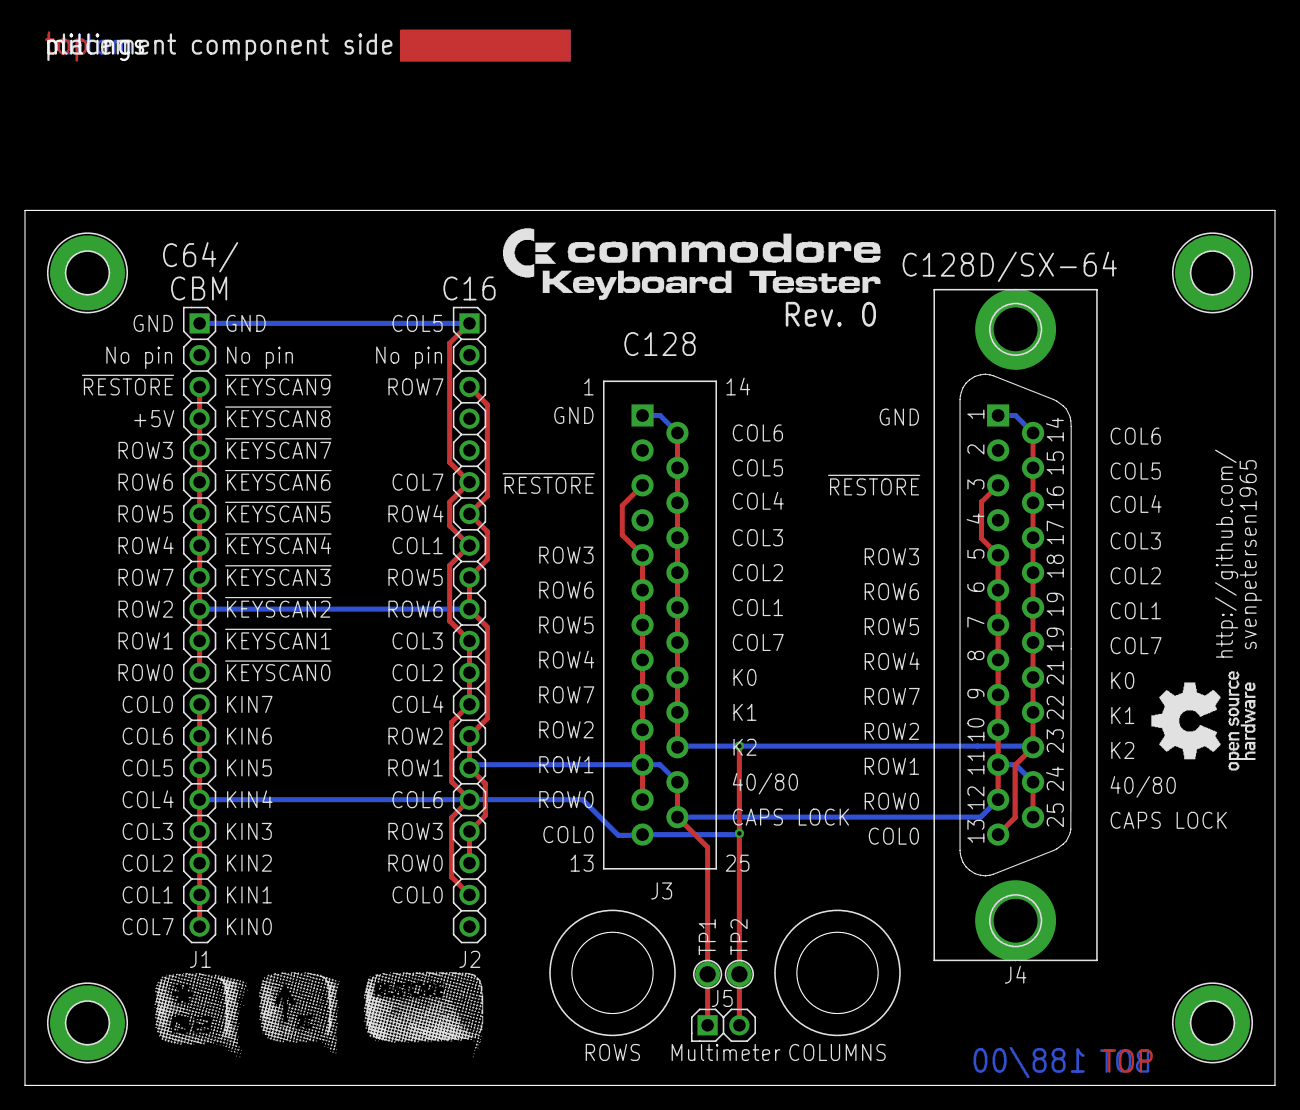
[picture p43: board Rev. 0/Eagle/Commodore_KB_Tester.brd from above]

Board: 2 copper layers, 100.0 x 70.0 mm, 16 parts (0 on the bottom side), 2 nets.

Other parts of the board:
U$13: C64_KEYS
U$14: 2LAYER
U$15: PCB-TITLE/
U$16: COMMODORE_KB

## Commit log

2022-08-17 initial upload
    [C=KB-Tester_BOM_v1_0.xlsx, Commodore_KB_Tester.brd, Commodore_KB_Tester.csv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]
2023-05-28 Rev. 2 released
    [C=KB-Tester_BOM_v1_0_calc_20220823.xlsx, C=KB-Tester_BOM_v2_0.xlsx, Commodore_KB_Tester.brd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]
